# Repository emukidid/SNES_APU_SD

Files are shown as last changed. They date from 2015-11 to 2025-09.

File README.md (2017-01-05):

# SNES_APU_SD
Drives a SNES APU from early Super Nintendo/Super Famicom consoles with an arduino to load tracks from SD Card

Based on code written by [CaitSith2]

### Current Features
- Loads a .spc file from SD card and plays it on the SNES APU
- Loads a .spc file through the PC interface.
- 16x2 LCD for track display and menu
- Menu with file selection
- SRAM to cache tracks (CaitSith2)
- Interface APU as direct memory (CaitSith2)

### Planned Features
- RTC for nice things

### Hardware required
- Early NTSC SNES or Super Famicom with modular APU
- Arduino Mega
- APU Arduino Shield (Work In Progress)
- Love for 16-bit SNES music

[caitsith2]:  <https://www.caitsith2.com/snes/apu.htm>

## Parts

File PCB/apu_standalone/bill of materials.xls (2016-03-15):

Digi-Key Part Number | Manufacturer | Manufacturer Part Number | Customer Reference | Quantity 1 | Quantity 2 | Quantity 3 | Mfg Std Lead Time | Description | Comments | RoHS Status | Lead Free Status | REACH Status
CP-1401-ND | CUI INC | RCJ-012 | RIGHT RCA | 1 | 0 | 0 | 8 Weeks | CONN RCA JACK METAL R/A RED PCB |  | RoHS Compliant | Lead free | Not Available
CP-1402-ND | CUI INC | RCJ-013 | LEFT RCA | 1 | 0 | 0 | 8 Weeks | CONN RCA JACK METAL R/A WHT PCB |  | RoHS Compliant | Lead free | Not Available
CP1-3533N-ND | CUI INC | SJ1-3533N | HEADPHONE, LINEOUT | 2 | 0 | 0 | 9 Weeks | CONN JACK STEREO R/A 3PIN 3.5MM |  | RoHS Compliant | Lead free | Not Available
SY033-ND | FDK AMERICA INC | CR1220 | RTC BATTERY | 1 | 0 | 0 | 16 Weeks | BATTERY LITHIUM 3V COIN 12.5MM |  | RoHS compliant by exemption | Lead free | Not Available
1276-1007-1-ND | SAMSUNG ELECTRO-MECHANICS AMERICA, INC (VA) | CL21F104ZBCNNNC | C1, C2, C7, C15..C19, C22..C31 | 18 | 0 | 0 | 13 Weeks | CAP CER 0.1UF 50V Y5V 0805 | Alternate Packaging Exists | RoHS Compliant | Lead free | Unaffected Dec-2014
311-1.0KARCT-ND | YAGEO (VA) | RC0805JR-071KL | R6, R26, R27 | 3 | 0 | 0 | 22 Weeks | RES SMD 1K OHM 5% 1/8W 0805 | Alternate Packaging Exists | RoHS Compliant | Lead free | Unaffected Jun-2015
475-1415-1-ND | OSRAM OPTO SEMICONDUCTORS INC(VA) | LH R974-LP-1 | ACT, RX, TX | 3 | 0 | 0 | 12 Weeks | LED RED DIFFUSED 0805 SMD | Alternate Packaging Exists | RoHS Compliant | Lead free | Unaffected Jun-2015
SW400-ND | OMRON ELECTRONICS INC-EMC DIV | B3F-1000 |  | 8 | 0 | 0 | 14 Weeks | SWITCH TACTILE SPST-NO 0.05A 24V |  | RoHS Compliant | Lead free | Not Available
WM12834CT-ND | MOLEX, LLC (VA) | 5031821852 | SD HOLDER | 1 | 0 | 0 | 8 Weeks | MICRO SD NORMAL ULTRALOWPRO8CKTE | Alternate Packaging Exists | RoHS Compliant | Lead free | Not Available
568-8150-1-ND | NXP SEMICONDUCTORS (VA) | 74HC4050D,653 | IC2 | 1 | 0 | 0 | 16 Weeks | IC HEX LEVEL SHIFTER 16SOIC | Alternate Packaging Exists | RoHS Compliant | Lead free | Unaffected Jun-2015
296-18476-1-ND | TEXAS INSTRUMENTS (VA) | LP2985-33DBVR | LP298X | 1 | 0 | 0 | 6 Weeks | IC REG LDO 3.3V 0.15A SOT23-5 | Alternate Packaging Exists | RoHS Compliant | Lead free | Unaffected Dec-2014
399-3684-1-ND | KEMET (VA) | T491A106K010AT | C8 | 1 | 0 | 0 | 2 Weeks | CAP TANT 10UF 10V 10% 1206 | Alternate Packaging Exists | RoHS Compliant | Lead free | Unaffected Jun-2014
296-4612-1-ND | TEXAS INSTRUMENTS (VA) | SN74AHC573DWR | IC1 | 1 | 0 | 0 | 6 Weeks | IC OCT TRNSP D-TYP LATCH 20-SOIC | Alternate Packaging Exists | RoHS Compliant | Lead free | Unaffected Dec-2014
706-1041-ND | ISSI | IS62C1024AL-35QLI | IC11 | 1 | 0 | 0 | 10 Weeks | IC SRAM 1MBIT 35NS 32SOP | Alternate Packaging Exists | RoHS Compliant | Lead free | Unaffected Dec-2014
SAM1067-50-ND | SAMTEC INC | TSW-150-17-T-S | 8-8-8-8-8-10 | 1 | 0 | 0 | 2 Weeks | CONN HEADER 50POS .100" SNGL TIN |  | RoHS Compliant | Lead free | Unaffected Jun-2015
SAM1067-36-ND | SAMTEC INC (VA) | TSW-136-17-T-S | 18-18 | 1 | 0 | 0 |  | CONN HEADER 36POS .100" SNGL TIN | No delivery date available | RoHS Compliant | Lead free | Unaffected Jun-2015
3306W-103-ND | BOURNS INC | 3306W-1-103 | 10K TRIM POT | 1 | 0 | 0 | 18 Weeks | TRIMMER 10K OHM 0.2W PC PIN |  | RoHS Compliant | Lead free | Unaffected Jun-2015
NHD-0216BZ-FL-YBW-ND | NEWHAVEN DISPLAY INTL | NHD-0216BZ-FL-YBW | LCD | 1 | 0 | 0 | 16 Weeks | LCD MOD CHAR 2X16 Y/G TRANSFL |  | RoHS Compliant | Lead free | Unaffected Jun-2015
311-10KARCT-ND | YAGEO (VA) | RC0805JR-0710KL | R2,R3,R7,R10,R11,R12,R13,R14,R15 | 9 | 0 | 0 | 22 Weeks | RES SMD 10K OHM 5% 1/8W 0805 | Alternate Packaging Exists | RoHS Compliant | Lead free | Unaffected Jun-2015
311-2.2KARCT-ND | YAGEO (VA) | RC0805JR-072K2L | R8, R9 | 2 | 0 | 0 | 22 Weeks | RES SMD 2.2K OHM 5% 1/8W 0805 | Alternate Packaging Exists | RoHS Compliant | Lead free | Unaffected Jun-2015
311-22KARCT-ND | YAGEO (VA) | RC0805JR-0722KL | R16, R17, R18, R19, R20, R21 | 6 | 0 | 0 | 22 Weeks | RES SMD 22K OHM 5% 1/8W 0805 | Alternate Packaging Exists | RoHS Compliant | Lead free | Unaffected Jun-2015
311-5.1KARCT-ND | YAGEO (VA) | RC0805JR-075K1L | R22, R23 | 2 | 0 | 0 | 22 Weeks | RES SMD 5.1K OHM 5% 1/8W 0805 | Alternate Packaging Exists | RoHS Compliant | Lead free | Unaffected Jun-2015
311-49.9CRCT-ND | YAGEO (VA) | RC0805FR-0749R9L | R4, R5 | 2 | 0 | 0 | 22 Weeks | RES SMD 49.9 OHM 1% 1/8W 0805 | Alternate Packaging Exists | RoHS Compliant | Lead free | Unaffected Jun-2015
497-1561-1-ND | STMICROELECTRONICS (VA) | LM2904DT | IC7 | 1 | 0 | 0 | 12 Weeks | IC OPAMP GP 1.1MHZ 8SO | Alternate Packaging Exists | RoHS Compliant | Lead free | Unaffected Jul-2011
DS1307Z+T&RCT-ND | MAXIM INTEGRATED (VA) | DS1307Z+T&R | IC3 | 1 | 0 | 0 | 10 Weeks | IC RTC CLK/CALENDAR I2C 8-SOIC | Alternate Packaging Exists | RoHS Compliant | Lead free | Unaffected Jun-2012
XC1911CT-ND | ECS INC (VA) | ECS-.327-12.5-13FLX-C | Q1 | 1 | 0 | 0 | 14 Weeks | CRYSTAL 32.7680KHZ 12.5PF SMD | Alternate Packaging Exists | RoHS Compliant | Lead free | Unaffected Dec-2014
BK-885-CT-ND | MEMORY PROTECTION DEVICES (VA) | BK-885-TR | CR1220 | 1 | 0 | 0 | 10 Weeks | HOLDER COIN CELL 12MM SMD | Alternate Packaging Exists | RoHS Compliant | Lead free | Unaffected Jun-2015
311-1365-1-ND | YAGEO (VA) | CC0805KKX7R7BB105 | C3,C4,C5,C6 | 4 | 0 | 0 | 21 Weeks | CAP CER 1UF 16V X7R 0805 | Alternate Packaging Exists | RoHS Compliant | Lead free | Unaffected Jun-2015
399-1136-1-ND | KEMET (VA) | C0805C102J5GACTU | C9,C12 | 2 | 0 | 0 | 10 Weeks | CAP CER 1000PF 50V NP0 0805 | Alternate Packaging Exists | RoHS Compliant | Lead free | Unaffected Jun-2014
399-1122-1-ND | KEMET (VA) | C0805C101J5GACTU | C10,C13 | 2 | 0 | 0 | 5 Weeks | CAP CER 100PF 50V NP0 0805 | Alternate Packaging Exists | RoHS Compliant | Lead free | Unaffected Jun-2014
311-1092-1-ND | YAGEO (VA) | CC0805CRNPO9BN3R0 | C20,C21 | 2 | 0 | 0 | 21 Weeks | CAP CER 3PF 50V NPO 0805 | Alternate Packaging Exists | RoHS Compliant | Lead free | Unaffected Jun-2015
445-7505-1-ND | TDK CORPORATION (VA) | C2012C0G1H182J060AA | C11,C14 | 2 | 0 | 0 | 12 Weeks | CAP CER 1800PF 50V C0G 0805 | Alternate Packaging Exists | RoHS Compliant | Lead free | Unaffected Jun-2015
706-1043-ND | ISSI | IS62C256AL-45ULI | IC8, IC9 | 2 | 0 | 0 | 12 Weeks | IC SRAM 256KBIT 45NS 28SOP | Alternate Packaging Exists | RoHS Compliant | Lead free | Unaffected Dec-2014
3M9454-ND | 3M | 961116-6404-AR | LCD MALE PINS | 1 | 0 | 0 | 8 Weeks | CONN HEADER VERT SGL 16POS GOLD |  | RoHS Compliant | Lead free | Not Available
S7049-ND | SULLINS CONNECTOR SOLUTIONS | PPPC161LFBN-RC | LCD FEMALE SOCKET | 1 | 0 | 0 | 4 Weeks | CONN HEADER FMALE 16POS .1" GOLD |  | RoHS Compliant | Lead free | Unaffected Dec-2014
ATMEGA2560-16AU-ND | ATMEL | ATMEGA2560-16AU | IC12 | 1 | 0 | 0 | 6 Weeks | IC MCU 8BIT 256KB FLASH 100TQFP | Alternate Packaging Exists | RoHS Compliant | Lead free | Unaffected Jun-2015
768-1007-1-ND | FTDI (VA) | FT232RL-REEL | IC15 | 1 | 0 | 0 | 12 Weeks | IC USB FS SERIAL UART 28-SSOP | Alternate Packaging Exists | RoHS Compliant | Lead free | Unaffected Jun-2015
ED2983-ND | ON SHORE TECHNOLOGY INC | USB-B1HSB6 | X4 | 1 | 0 | 0 | 8 Weeks | CONN USB TYPE B R/A BLACK |  | RoHS Compliant | Lead free | Unaffected Jun-2015
535-10008-1-ND | ABRACON LLC (VA) | AWSCR-16.00CV-T | Y1 | 1 | 0 | 0 | 11 Weeks | RESONATOR CER 16.00MHZ W/CAP SMD | Alternate Packaging Exists | RoHS Compliant | Lead free | Unaffected Jun-2015
311-1.00MCRCT-ND | YAGEO (VA) | RC0805FR-071ML | R1 | 1 | 0 | 0 | 22 Weeks | RES SMD 1M OHM 1% 1/8W 0805 | Alternate Packaging Exists | RoHS Compliant | Lead free | Unaffected Jun-2015
283-3140-1-ND | EATON BUSSMANN (VA) | PTS120615V050 | F1 | 1 | 0 | 0 | 11 Weeks | PTC RESETTABLE SMD 1206 15V 0.5A |  | RoHS Compliant | Lead free | Unaffected Jul-2011

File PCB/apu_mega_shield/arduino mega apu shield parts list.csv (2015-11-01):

QTY | Part | Digikey Part Number
1 | RCA Red | CP-1401-ND
1 | RCA White | CP-1402-ND
2 | 3.5mm female TRS | CP1-3533N-ND
2 | 50ohm resistor | 51QBK-ND
4 | 1uF capacitor | BC1162CT-ND
1 | 32.768 khz crystal | X1123-ND
1 | DS1307 RTC | DS1307+-ND
1 | CR1220 holder | BK-890-ND
2 | 2.2K resistor | 2.2KQBK-ND
3 | 0.1uF Capacitor,(0805) | 1276-1007-1-ND
1 | 1K resistor (0805) | 311-1.0KARCT-ND
1 | Red LED,(0805) | 475-1415-1-ND
8 | buttons | SW400-ND
1 | Micro SD holder | WM10795CT-ND
1 | 4050D buffer chip | 568-8150-1-ND
1 | LP298X 3.3v Regulator | 296-18476-1-ND
1 | 10uF 10V Capacitor (1206) | 399-3684-1-ND
1 | 74HCT573 Octal Latch | 296-4612-1-ND
1 | IS62C1024AL-35QLI Sram chip | 706-1041-ND
1 | 50 pin breakaway headers | SAM1067-50-ND
1 | 36 pin breakaway headers | SAM1067-36-ND
1 | 16 pin header | SAM1067-16-ND
1 | 16 pin socket | SAM1198-16-ND
1 | 10K trim pot | 3306W-103-ND
1 | 10K 9 resistor network. | 4610X-1-103LF-ND
1 | 16x2 LCD character display. | NHD-0216BZ-FL-YBW-ND
1 | 220ohm resistor | 220QBK-ND

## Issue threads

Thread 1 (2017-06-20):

Interested in...

thErZAgH, 2017-06-20:
Hi.

I'm highly interested in using the awesome player on Arduino Uno. Is this possible? Which version of Arduino can I use to compile the code for Arduino Uno?

Thank you in advance...

ZapDragon, 2018-12-29:
Simply, you cannot use an Uno. It just doesnt have the pins needed for this setup.
SD card, LCD, Buttons, APU Interface, SRAM, ect.
There is just too much happening.

I am building this myself, and I understand why a Mega is used. If you want to build this I strongly recommend following everything in the source files to the letter.

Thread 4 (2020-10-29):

SPC play issue

VargSilvermane, 2020-10-29:
When playing a track the first note is played, hangs on the note and fades after a second. No further notes are played.

Hardware used:
Mega Shield with integrated APU
Arduino Mega 2560 r3

Software:
Arduino IDE 1.8.13
SDFAT by Bill Greiman
RTClib by Adafruit

emukidid, 2020-10-31:
Try messing with the PRESCALER value in the .ino, some mega clones have issues with the default speed.

VargSilvermane, 2020-10-31:
No luck, I tried a prescaler of 1 and 2. I should also mention the arduino _should_ be a genuine unit, barring an counterfeit chip on arduinos product, seeing as I purchased it from them.

Oj5000, 2021-11-12:
Any luck getting this working? Could be to do with the changes made in v3 of the hardware

VargSilvermane, 2021-12-05:
Yes, though it was a while ago. Trying to remember, I believe it had to do with the SDFAT library and compatibility with various capacity SD cards. I ended up swapping out the library with another version and managed to get it working well. Incidentally I remade the hardware into a more portable format since the original post. (handheld case with upgraded screen and battery/charger)

Closed 2021-12-05.

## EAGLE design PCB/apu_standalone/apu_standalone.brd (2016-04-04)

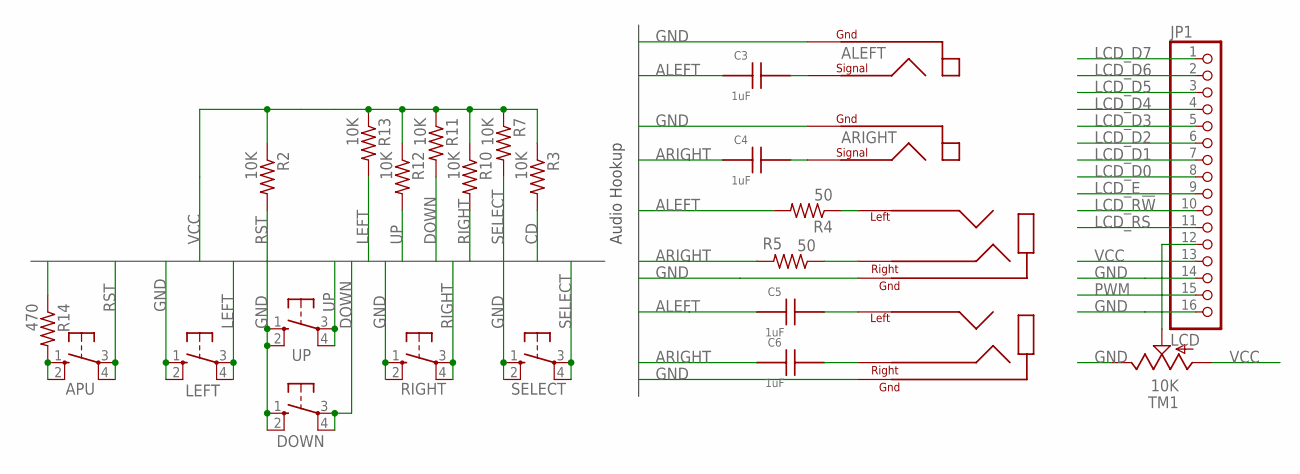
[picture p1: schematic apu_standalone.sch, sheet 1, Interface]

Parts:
APU: Reset; B3F-10XX
C3, C4, C5, C6: 1uF; C0805
DOWN: DOWN; B3F-10XX
JP1: LCD; 1X16
LEFT: LEFT; B3F-10XX
R2, R3, R7, R10, R11, R12, R13: 10K; R0805
R4, R5: 50; R0805
R14: 470; R0805
RIGHT: RIGHT; B3F-10XX
SELECT: SELECT; B3F-10XX
TM1: 10K; CA6H
U$2, U$3: HEADPHONE; SJ1-3533N
U$4, U$5: RCA; RCJ-01X
UP: UP; B3F-10XX

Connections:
ALEFT: C3.1, C5.1, R4.2; also elsewhere on the board
ARIGHT: C4.1, C6.1, R5.2; also elsewhere on the board
CD: R3.2; also elsewhere on the board
DOWN: DOWN.3, DOWN.4 (P1), R11.2; also elsewhere on the board
GND: DOWN.1 (S), DOWN.2 (S1), JP1.14, JP1.16, LEFT.1 (S), LEFT.2 (S1), R14.1, RIGHT.1 (S), RIGHT.2 (S1), SELECT.1 (S), SELECT.2 (S1), TM1.E, U$2.GND, U$3.GND, U$4.PGND1, U$4.PGND2, U$4.PGND3, U$5.PGND1, U$5.PGND2, U$5.PGND3, UP.1 (S), UP.2 (S1); also elsewhere on the board
LCD_D0: JP1.8; also elsewhere on the board
LCD_D1: JP1.7; also elsewhere on the board
LCD_D2: JP1.6; also elsewhere on the board
LCD_D3: JP1.5; also elsewhere on the board
LCD_D4: JP1.4; also elsewhere on the board
LCD_D5: JP1.3; also elsewhere on the board
LCD_D6: JP1.2; also elsewhere on the board
LCD_D7: JP1.1; also elsewhere on the board
LCD_E: JP1.9; also elsewhere on the board
LCD_R!W: JP1.10; also elsewhere on the board
LCD_RS: JP1.11; also elsewhere on the board
LEFT: LEFT.3, LEFT.4 (P1), R13.2; also elsewhere on the board
unnamed: C3.2, U$4.PSIG
unnamed: C4.2, U$5.PSIG
unnamed: C5.2, U$3.LEFT
unnamed: APU.1 (S), APU.2 (S1), R14.2
unnamed: C6.2, U$3.RIGHT
unnamed: R4.1, U$2.LEFT
unnamed: R5.1, U$2.RIGHT
unnamed: JP1.12, TM1.S
PWM: JP1.15; also elsewhere on the board
RIGHT: R10.2, RIGHT.3, RIGHT.4 (P1); also elsewhere on the board
RST: APU.3, APU.4 (P1), R2.2; also elsewhere on the board
SELECT: R7.2, SELECT.3, SELECT.4 (P1); also elsewhere on the board
UP: R12.2, UP.3, UP.4 (P1); also elsewhere on the board
VCC: JP1.13, R2.1, R3.1, R7.1, R10.1, R11.1, R12.1, R13.1, TM1.A; also elsewhere on the board

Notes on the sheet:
Audio Hookup

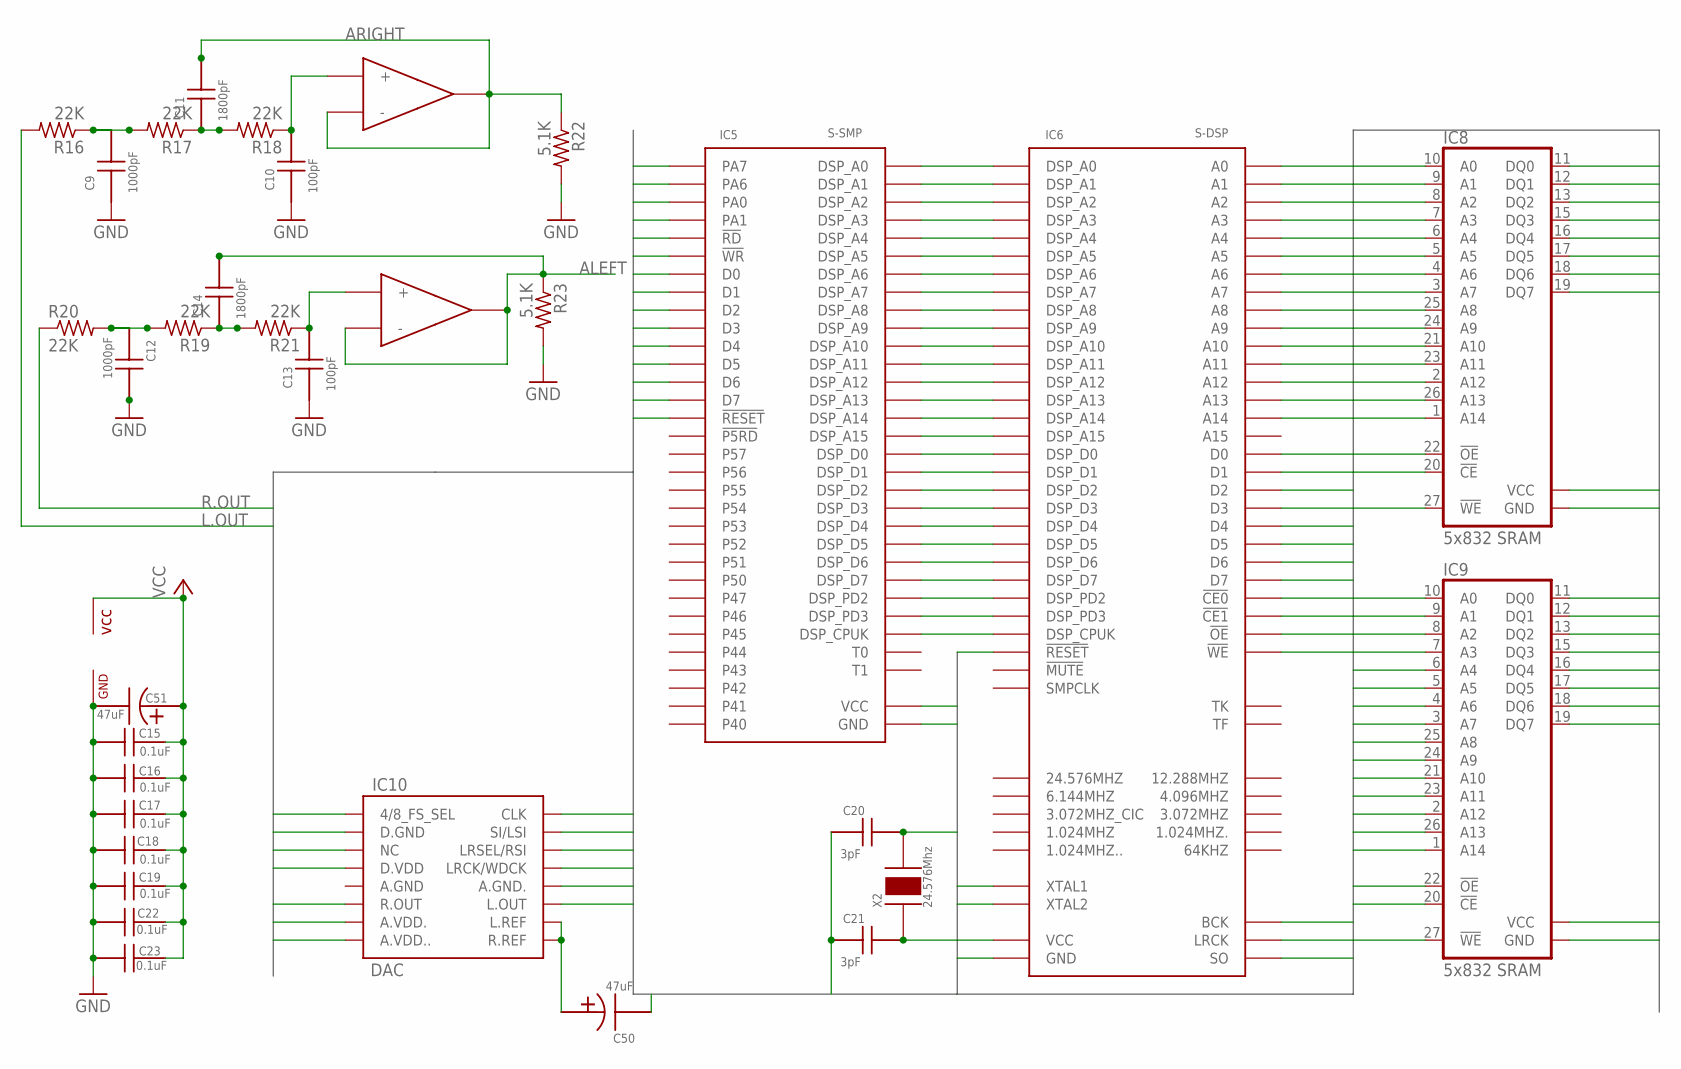
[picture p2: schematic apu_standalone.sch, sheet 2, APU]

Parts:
C9, C12: 1000pF; C0805
C10, C13: 100pF; C0805
C11, C14: 1800pF; C0805
C15, C16, C17, C18, C19, C22, C23: 0.1uF; C0805
C20, C21: 3pF; C0805
C50, C51: 47uF; TT5D6
IC5: S-SMP; QFP64_SOT319
IC6: S-DSP; QFP80_SOT318
IC7: LM2904; SO-08
IC8, IC9: 5x832 SRAM; SO28X
IC10: DAC; SO16W
R16, R17, R18, R19, R20, R21: 22K; R0805
R22, R23: 5.1K; R0805
X2: 24.576Mhz; QS

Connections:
!CE0: IC6.28 (!CE0), IC8.20 (!CE)
!CE1: IC6.27 (!CE1), IC9.20 (!CE)
!OE: IC6.30 (!OE), IC8.22 (!OE), IC9.22 (!OE)
!RD: IC5.46 (!RD); also elsewhere on the board
!WE: IC6.36 (!WE), IC8.27 (!WE), IC9.27 (!WE)
!WR: IC5.47 (!WR); also elsewhere on the board
A10: IC5.49 (PA0); also elsewhere on the board
A11: IC5.48 (PA1); also elsewhere on the board
A15: IC5.51 (PA7); also elsewhere on the board
A18: IC6.9 (A0), IC8.10 (A0), IC9.10 (A0)
A19: IC6.10 (A1), IC8.9 (A1), IC9.9 (A1)
A20: IC6.11 (A2), IC8.8 (A2), IC9.8 (A2)
A21: IC6.13 (A3), IC8.7 (A3), IC9.7 (A3)
A22: IC6.14 (A4), IC8.6 (A4), IC9.6 (A4)
A23: IC6.15 (A5), IC8.5 (A5), IC9.5 (A5)
A24: IC6.16 (A6), IC8.4 (A6), IC9.4 (A6)
A25: IC6.17 (A7), IC8.3 (A7), IC9.3 (A7)
A26: IC6.34 (A8), IC8.25 (A8), IC9.25 (A8)
A27: IC6.32 (A9), IC8.24 (A9), IC9.24 (A9)
A28: IC6.29 (A10), IC8.21 (A10), IC9.21 (A10)
A29: IC6.31 (A11), IC8.23 (A11), IC9.23 (A11)
A30: IC6.18 (A12), IC8.2 (A12), IC9.2 (A12)
A31: IC6.35 (A13), IC8.26 (A13), IC9.26 (A13)
A32: IC6.19 (A14), IC8.1 (A14), IC9.1 (A14)
A.REF: C50.+, IC10.9 (R.REF), IC10.10 (L.REF)
ALEFT: C14.2, IC7.6 (-), IC7.7 (OUT), R23.1; also elsewhere on the board
ARIGHT: C11.2, IC7.1 (OUT), IC7.2 (-), R22.1; also elsewhere on the board
BCK: IC6.42 (BCK), IC10.16 (CLK)
D0: IC5.45 (D0); also elsewhere on the board
D1: IC5.44 (D1); also elsewhere on the board
D2: IC5.43 (D2); also elsewhere on the board
D3: IC5.42 (D3); also elsewhere on the board
D4: IC5.41 (D4); also elsewhere on the board
D5: IC5.40 (D5); also elsewhere on the board
D6: IC5.39 (D6); also elsewhere on the board
D7: IC5.38 (D7); also elsewhere on the board
D8: IC6.8 (D0), IC8.11 (DQ0), IC9.11 (DQ0)
D9: IC6.7 (D1), IC8.12 (DQ1), IC9.12 (DQ1)
D10: IC6.6 (D2), IC8.13 (DQ2), IC9.13 (DQ2)
D11: IC6.22 (D3), IC8.15 (DQ3), IC9.15 (DQ3)
D12: IC6.23 (D4), IC8.16 (DQ4), IC9.16 (DQ4)
D13: IC6.24 (D5), IC8.17 (DQ5), IC9.17 (DQ5)
D14: IC6.25 (D6), IC8.18 (DQ6), IC9.18 (DQ6)
D15: IC6.26 (D7), IC8.19 (DQ7), IC9.19 (DQ7)
DSP_A0: IC5.5 (DSP_A0), IC6.60 (DSP_A0)
DSP_A1: IC5.4 (DSP_A1), IC6.61 (DSP_A1)
DSP_A2: IC5.3 (DSP_A2), IC6.62 (DSP_A2)
DSP_A3: IC5.2 (DSP_A3), IC6.63 (DSP_A3)
DSP_A4: IC5.1 (DSP_A4), IC6.64 (DSP_A4)
DSP_A5: IC5.64 (DSP_A5), IC6.65 (DSP_A5)
DSP_A6: IC5.63 (DSP_A6), IC6.66 (DSP_A6)
DSP_A7: IC5.62 (DSP_A7), IC6.67 (DSP_A7)
DSP_A8: IC5.61 (DSP_A8), IC6.68 (DSP_A8)
DSP_A9: IC5.60 (DSP_A9), IC6.69 (DSP_A9)
DSP_A10: IC5.59 (DSP_A10), IC6.70 (DSP_A10)
DSP_A11: IC5.56 (DSP_A11), IC6.71 (DSP_A11)
DSP_A12: IC5.55 (DSP_A12), IC6.72 (DSP_A12)
DSP_A13: IC5.54 (DSP_A13), IC6.74 (DSP_A13)
DSP_A14: IC5.53 (DSP_A14), IC6.75 (DSP_A14)
DSP_A15: IC5.52 (DSP_A15), IC6.76 (DSP_A15)
DSP_CPUK: IC5.16 (DSP_CPUK), IC6.48 (DSP_CPUK)
DSP_D0: IC5.13 (DSP_D0), IC6.51 (DSP_D0)
DSP_D1: IC5.12 (DSP_D1), IC6.53 (DSP_D1)
DSP_D2: IC5.11 (DSP_D2), IC6.54 (DSP_D2)
DSP_D3: IC5.10 (DSP_D3), IC6.55 (DSP_D3)
DSP_D4: IC5.9 (DSP_D4), IC6.56 (DSP_D4)
DSP_D5: IC5.8 (DSP_D5), IC6.57 (DSP_D5)
DSP_D6: IC5.7 (DSP_D6), IC6.58 (DSP_D6)
DSP_D7: IC5.6 (DSP_D7), IC6.59 (DSP_D7)
DSP_PD2: IC5.15 (DSP_PD2), IC6.49 (DSP_PD2)
DSP_PD3: IC5.14 (DSP_PD3), IC6.50 (DSP_PD3)
GND: C9.1, C10.1, C12.2, C13.1, C15.2, C16.2, C17.2, C18.2, C19.2, C20.1, C21.1, C22.1, C23.2, C50.-, C51.-, IC5.26 (GND), IC5.58 (GND), IC6.12 (GND), IC6.52 (GND), IC7.4 (GND), IC8.14 (GND), IC9.14 (GND), IC10.1 (4/8_FS_SEL), IC10.2 (D.GND), IC10.12 (A.GND.), IC10.14 (LRSEL/RSI), R22.2, R23.2; also elsewhere on the board
L1: C12.1, R19.2, R20.2
L2: C14.1, R19.1, R21.2
L3: C13.2, IC7.5 (+), R21.1
L.OUT: IC10.11 (L.OUT), R16.2
LRCK: IC6.43 (LRCK), IC10.13 (LRCK/WDCK)
R1: C9.2, R16.1, R17.2
R2: C11.1, R17.1, R18.2
R3: C10.2, IC7.3 (+), R18.1
R.OUT: IC10.6 (R.OUT), R20.1
RST: IC5.37 (!RESET), IC6.47 (!RESET); also elsewhere on the board
SO: IC6.44 (SO), IC10.15 (SI/LSI)
VCC: C15.1, C16.1, C17.1, C18.1, C19.1, C22.2, C23.1, C51.+, IC5.50 (PA6), IC5.57 (VCC), IC6.33 (VCC), IC6.73 (VCC), IC7.8 (VCC), IC8.28 (VCC), IC9.28 (VCC), IC10.3 (NC), IC10.4 (D.VDD), IC10.7 (A.VDD.), IC10.8 (A.VDD..); also elsewhere on the board
XTAL1: C21.2, IC6.45 (XTAL1), X2.1
XTAL2: C20.2, IC6.46 (XTAL2), X2.2

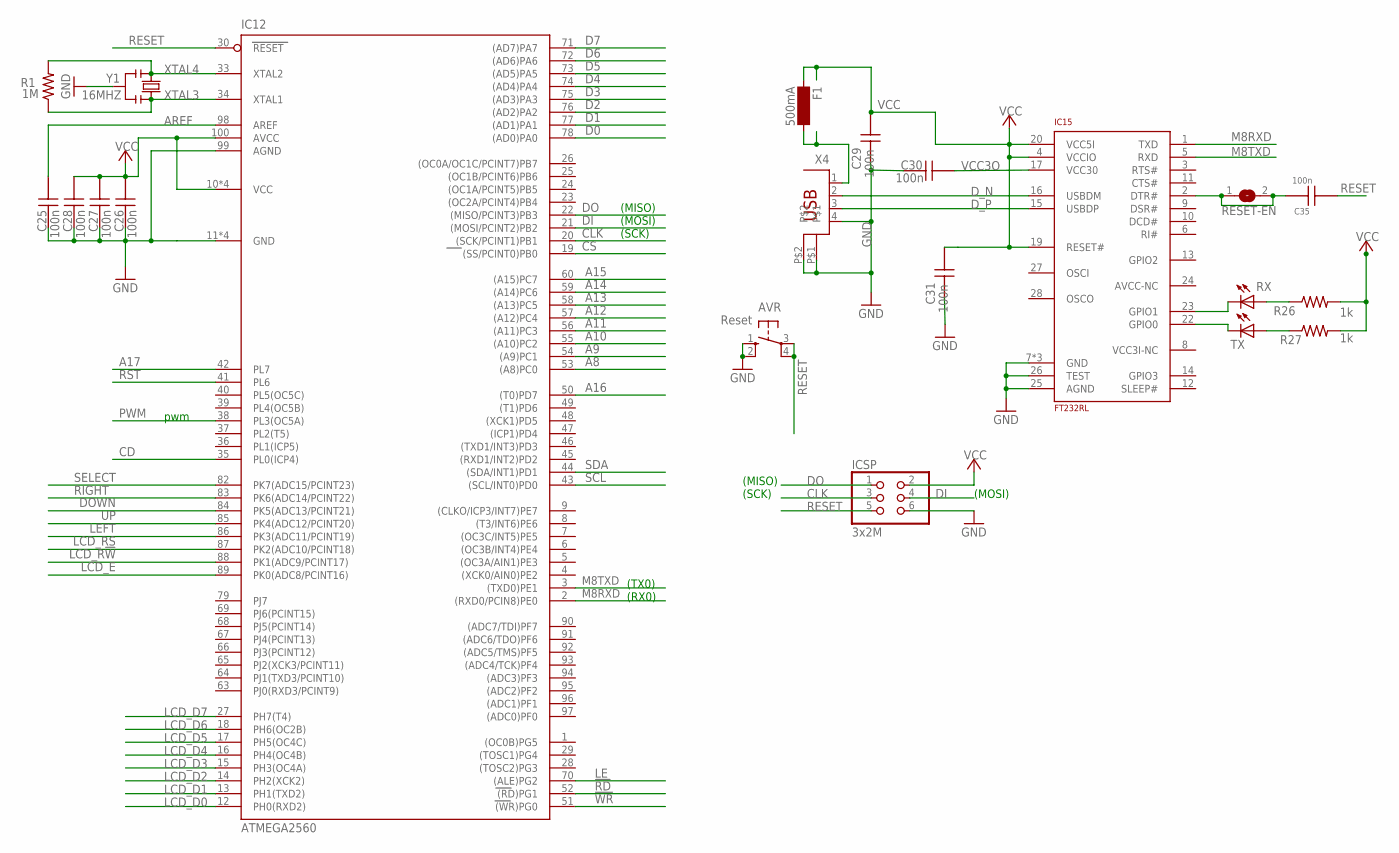
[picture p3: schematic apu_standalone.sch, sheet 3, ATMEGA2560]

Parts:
AVR: Reset; B3F-10XX
C25, C26, C27, C28, C29, C30, C31, C35: 100n; C0805
F1: 500mA; SM-1206
IC12: ATMEGA2560; TQFP100
IC15: FT232RL; SSOP28
ICSP: 3x2M; 2X03
R1: 1M; R0805
R26, R27: 1k; R0805
RESET-EN: SJ
RX: LEDCHIP-LED0805; CHIP-LED0805
TX: LEDCHIP-LED0805; CHIP-LED0805
X4: PN61729
Y1: 16MHZ; RESONATOR

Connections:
!RD: IC12.52 ((RD)PG1); also elsewhere on the board
!WR: IC12.51 ((WR)PG0); also elsewhere on the board
A8: IC12.53 ((A8)PC0); also elsewhere on the board
A9: IC12.54 ((A9)PC1); also elsewhere on the board
A10: IC12.55 ((A10)PC2); also elsewhere on the board
A11: IC12.56 ((A11)PC3); also elsewhere on the board
A12: IC12.57 ((A12)PC4); also elsewhere on the board
A13: IC12.58 ((A13)PC5); also elsewhere on the board
A14: IC12.59 ((A14)PC6); also elsewhere on the board
A15: IC12.60 ((A15)PC7); also elsewhere on the board
A16: IC12.50 ((T0)PD7); also elsewhere on the board
A17: IC12.42 (PL7); also elsewhere on the board
AREF: C25.1, IC12.98 (AREF)
CD: IC12.35 (PL0(ICP4)); also elsewhere on the board
CLK: IC12.20 ((SCK/PCINT1)PB1), ICSP.3; also elsewhere on the board
CS: IC12.19 ((SS/PCINT0)PB0); also elsewhere on the board
D0: IC12.78 ((AD0)PA0); also elsewhere on the board
D1: IC12.77 ((AD1)PA1); also elsewhere on the board
D2: IC12.76 ((AD2)PA2); also elsewhere on the board
D3: IC12.75 ((AD3)PA3); also elsewhere on the board
D4: IC12.74 ((AD4)PA4); also elsewhere on the board
D5: IC12.73 ((AD5)PA5); also elsewhere on the board
D6: IC12.72 ((AD6)PA6); also elsewhere on the board
D7: IC12.71 ((AD7)PA7); also elsewhere on the board
DI: IC12.21 ((MOSI/PCINT2)PB2), ICSP.4; also elsewhere on the board
DO: IC12.22 ((MISO/PCINT3)PB3), ICSP.1; also elsewhere on the board
DOWN: IC12.84 (PK5(ADC13/PCINT21)); also elsewhere on the board
DTR: C35.1, IC15.2 (DTR#), RESET-EN.1, RESET-EN.2
D_N: IC15.16 (USBDM), X4.2
D_P: IC15.15 (USBDP), X4.3
GND: AVR.1 (S), AVR.2 (S1), C25.2, C26.2, C27.2, C28.2, C29.2, C30.1, C31.2, IC12.11 (GND), IC12.32 (GND), IC12.62 (GND), IC12.81 (GND), IC12.99 (AGND), IC15.7 (GND), IC15.18 (GND), IC15.21 (GND), IC15.25 (AGND), IC15.26 (TEST), ICSP.6, X4.4, X4.P$1, X4.P$2, Y1.2; also elsewhere on the board
LCD_D0: IC12.12 (PH0(RXD2)); also elsewhere on the board
LCD_D1: IC12.13 (PH1(TXD2)); also elsewhere on the board
LCD_D2: IC12.14 (PH2(XCK2)); also elsewhere on the board
LCD_D3: IC12.15 (PH3(OC4A)); also elsewhere on the board
LCD_D4: IC12.16 (PH4(OC4B)); also elsewhere on the board
LCD_D5: IC12.17 (PH5(OC4C)); also elsewhere on the board
LCD_D6: IC12.18 (PH6(OC2B)); also elsewhere on the board
LCD_D7: IC12.27 (PH7(T4)); also elsewhere on the board
LCD_E: IC12.89 (PK0(ADC8/PCINT16)); also elsewhere on the board
LCD_R!W: IC12.88 (PK1(ADC9/PCINT17)); also elsewhere on the board
LCD_RS: IC12.87 (PK2(ADC10/PCINT18)); also elsewhere on the board
LE: IC12.70 ((ALE)PG2); also elsewhere on the board
LEFT: IC12.86 (PK3(ADC11/PCINT19)); also elsewhere on the board
M8RXD: IC12.2 ((RXD0/PCIN8)PE0), IC15.1 (TXD)
M8TXD: IC12.3 ((TXD0)PE1), IC15.5 (RXD)
unnamed: IC15.23 (GPIO1), RX.C
unnamed: IC15.22 (GPIO0), TX.C
unnamed: R26.1, RX.A
unnamed: R27.1, TX.A
unnamed: F1.2, X4.1
PWM: IC12.38 (PL3(OC5A)); also elsewhere on the board
RESET: AVR.3, AVR.4 (P1), C35.2, IC12.30 (RESET), ICSP.5
RIGHT: IC12.83 (PK6(ADC14/PCINT22)); also elsewhere on the board
RST: IC12.41 (PL6); also elsewhere on the board
SCL: IC12.43 ((SCL/INT0)PD0); also elsewhere on the board
SDA: IC12.44 ((SDA/INT1)PD1); also elsewhere on the board
SELECT: IC12.82 (PK7(ADC15/PCINT23)); also elsewhere on the board
UP: IC12.85 (PK4(ADC12/PCINT20)); also elsewhere on the board
VCC: C26.1, C27.1, C28.1, C29.1, C31.1, F1.1, IC12.10 (VCC), IC12.31 (VCC), IC12.61 (VCC), IC12.80 (VCC), IC12.100 (AVCC), IC15.4 (VCCIO), IC15.19 (RESET#), IC15.20 (VCC5I), ICSP.2, R26.2, R27.2; also elsewhere on the board
VCC3O: C30.2, IC15.17 (VCC30)
XTAL3: IC12.34 (XTAL1), R1.1, Y1.3
XTAL4: IC12.33 (XTAL2), R1.2, Y1.1

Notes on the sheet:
pwm
(TX0)
(RX0)
(MISO)
(SCK)
(MOSI)

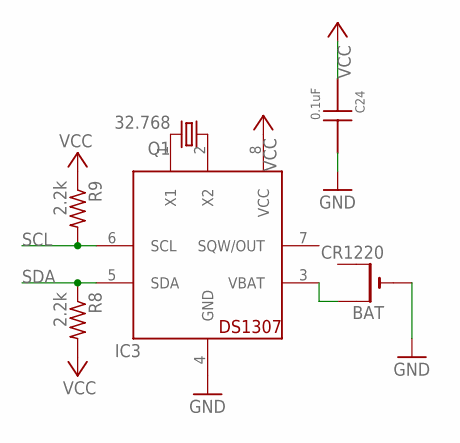
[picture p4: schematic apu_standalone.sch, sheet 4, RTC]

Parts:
BAT: CR1220; CR1220-SMD
C24: 0.1uF; C0805
IC3: DS1307; SO-08
Q1: 32.768; SMD
R8, R9: 2.2k; R0805

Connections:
GND: BAT.-, C24.2, IC3.4 (GND); also elsewhere on the board
unnamed: BAT.+$1 (+), IC3.3 (VBAT)
unnamed: IC3.1 (X1), Q1.2
unnamed: IC3.2 (X2), Q1.1
SCL: IC3.6 (SCL), R9.2; also elsewhere on the board
SDA: IC3.5 (SDA), R8.1; also elsewhere on the board
VCC: C24.1, IC3.8 (VCC), R8.2, R9.1; also elsewhere on the board

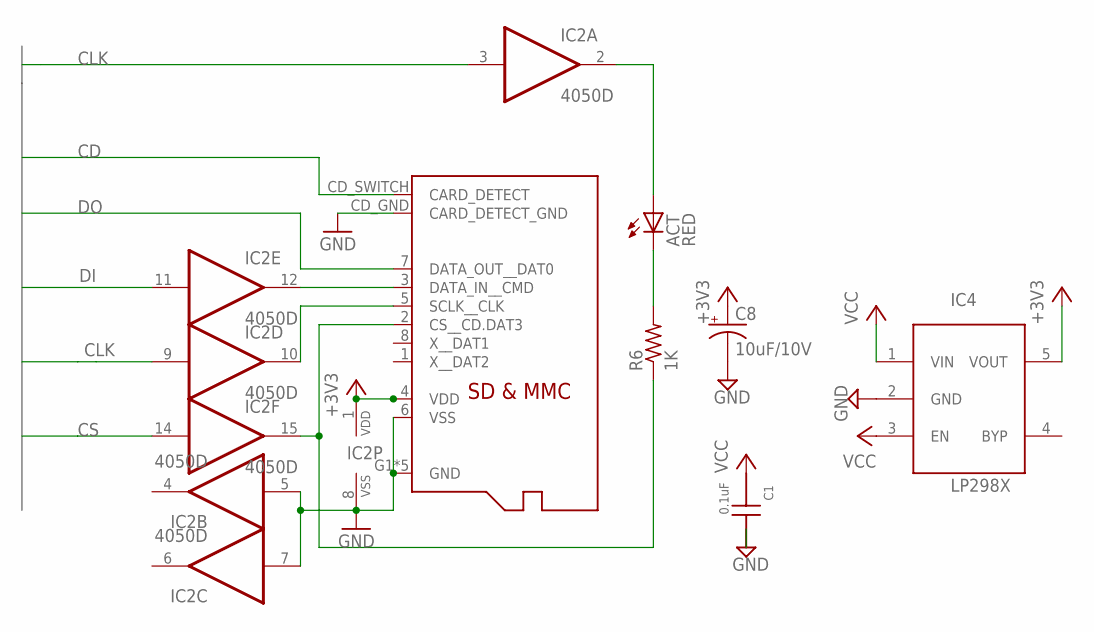
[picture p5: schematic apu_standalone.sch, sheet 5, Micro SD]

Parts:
ACT: RED; CHIP-LED0805
C1: 0.1uF; C0805
C8: 10uF/10V; A/3216-18R
IC2: 4050D; SO16
IC4: LP298XS; SOT23-5L
R6: 1K; R0805
U$1: MICROSD-2; MICROSD-3

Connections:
+3V3: C8.+, IC2.1 (VDD), IC4.5 (VOUT), U$1.4 (VDD)
BUF_CLK: IC2.10 (O), U$1.5 (SCLK__CLK)
BUF_CS: IC2.15 (O), R6.1, U$1.2 (CS__CD.DAT3)
BUF_DI: IC2.12 (O), U$1.3 (DATA_IN__CMD)
BUF_LED: ACT.A, IC2.2 (O)
CD: U$1.CD_SWITCH (CARD_DETECT); also elsewhere on the board
CLK: IC2.3 (I), IC2.9 (I); also elsewhere on the board
CS: IC2.14 (I); also elsewhere on the board
DI: IC2.11 (I); also elsewhere on the board
DO: U$1.7 (DATA_OUT__DAT0); also elsewhere on the board
GND: C1.2, C8.-, IC2.5 (I), IC2.7 (I), IC2.8 (VSS), IC4.2 (GND), U$1.6 (VSS), U$1.CD_GND (CARD_DETECT_GND), U$1.G1 (GND), U$1.G2 (GND), U$1.G3 (GND), U$1.G4 (GND), U$1.G5 (GND); also elsewhere on the board
unnamed: ACT.C, R6.2
VCC: C1.1, IC4.1 (VIN), IC4.3 (EN); also elsewhere on the board

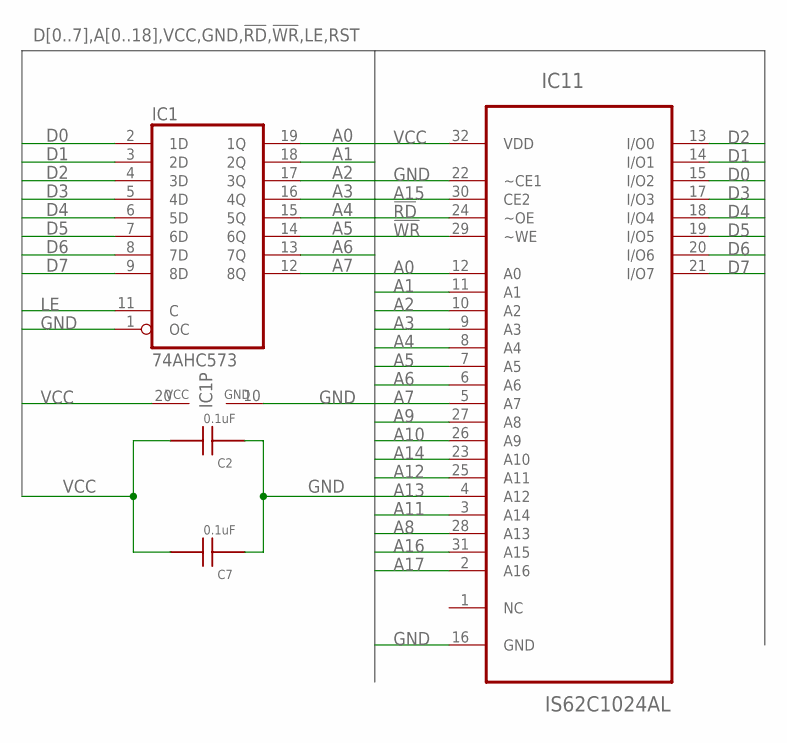
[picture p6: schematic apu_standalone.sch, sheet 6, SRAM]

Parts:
C2, C7: 0.1uF; C0805
IC1: 74AHC573; SO20W
IC11: IS62C1024AL; SOIC127P1412X305-32N

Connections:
!RD: IC11.24 (~OE); also elsewhere on the board
!WR: IC11.29 (~WE); also elsewhere on the board
A0: IC1.19 (1Q), IC11.12 (A0)
A1: IC1.18 (2Q), IC11.11 (A1)
A2: IC1.17 (3Q), IC11.10 (A2)
A3: IC1.16 (4Q), IC11.9 (A3)
A4: IC1.15 (5Q), IC11.8 (A4)
A5: IC1.14 (6Q), IC11.7 (A5)
A6: IC1.13 (7Q), IC11.6 (A6)
A7: IC1.12 (8Q), IC11.5 (A7)
A8: IC11.28 (A13); also elsewhere on the board
A9: IC11.27 (A8); also elsewhere on the board
A10: IC11.26 (A9); also elsewhere on the board
A11: IC11.3 (A14); also elsewhere on the board
A12: IC11.25 (A11); also elsewhere on the board
A13: IC11.4 (A12); also elsewhere on the board
A14: IC11.23 (A10); also elsewhere on the board
A15: IC11.30 (CE2); also elsewhere on the board
A16: IC11.31 (A15); also elsewhere on the board
A17: IC11.2 (A16); also elsewhere on the board
D0: IC1.2 (1D), IC11.15 (I/O2); also elsewhere on the board
D1: IC1.3 (2D), IC11.14 (I/O1); also elsewhere on the board
D2: IC1.4 (3D), IC11.13 (I/O0); also elsewhere on the board
D3: IC1.5 (4D), IC11.17 (I/O3); also elsewhere on the board
D4: IC1.6 (5D), IC11.18 (I/O4); also elsewhere on the board
D5: IC1.7 (6D), IC11.19 (I/O5); also elsewhere on the board
D6: IC1.8 (7D), IC11.20 (I/O6); also elsewhere on the board
D7: IC1.9 (8D), IC11.21 (I/O7); also elsewhere on the board
GND: C2.1, C7.1, IC1.1 (OC), IC1.10 (GND), IC11.16 (GND), IC11.22 (~CE1); also elsewhere on the board
LE: IC1.11 (C); also elsewhere on the board
VCC: C2.2, C7.2, IC1.20 (VCC), IC11.32 (VDD); also elsewhere on the board

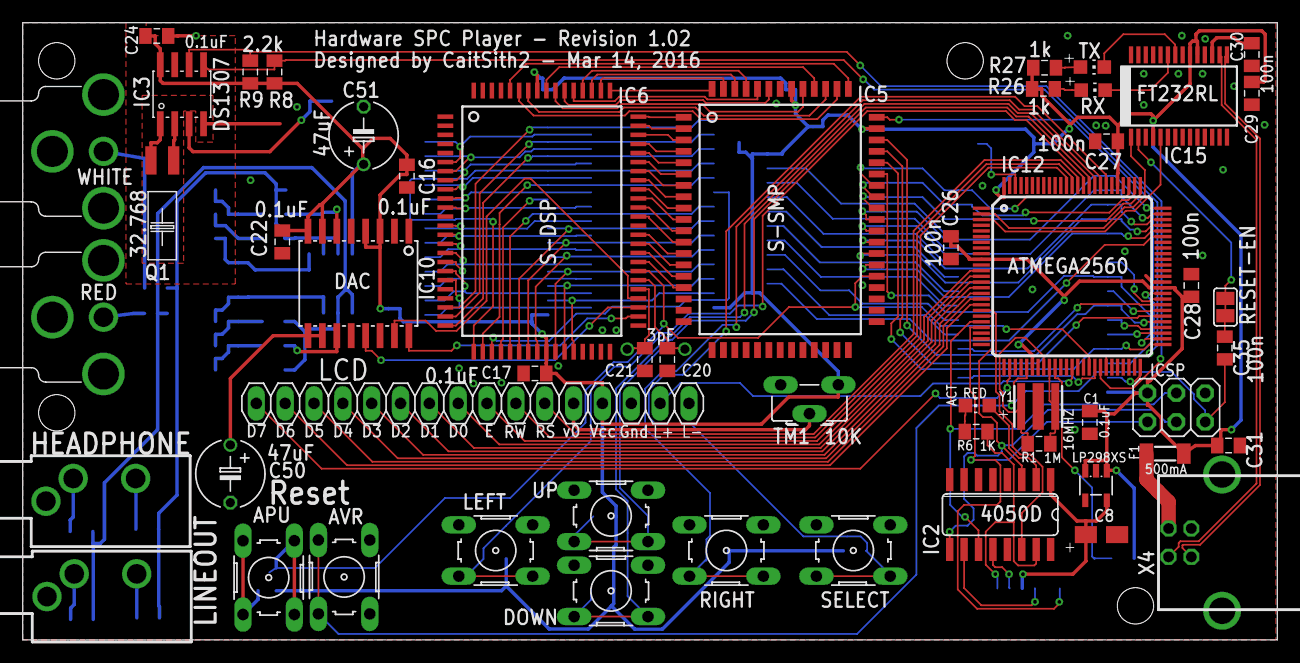
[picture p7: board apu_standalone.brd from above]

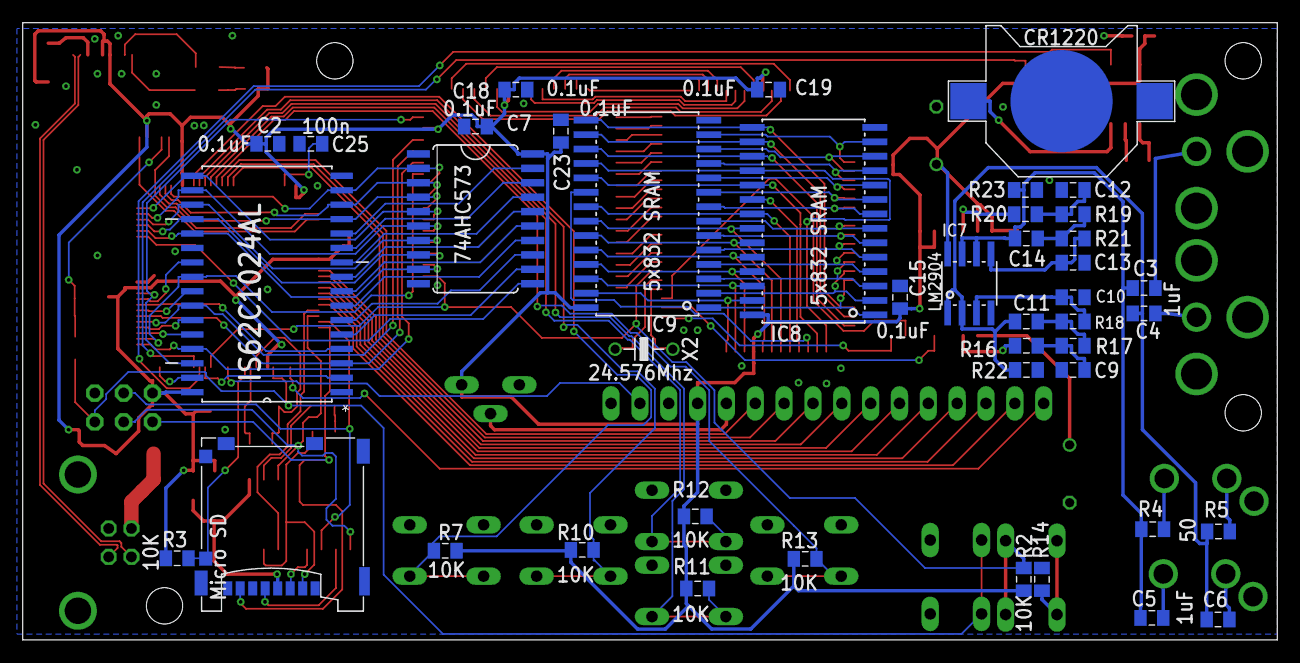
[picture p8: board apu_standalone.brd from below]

Board: 2 copper layers, 110.5 x 54.4 mm, 96 parts (43 on the bottom side), 158 nets.

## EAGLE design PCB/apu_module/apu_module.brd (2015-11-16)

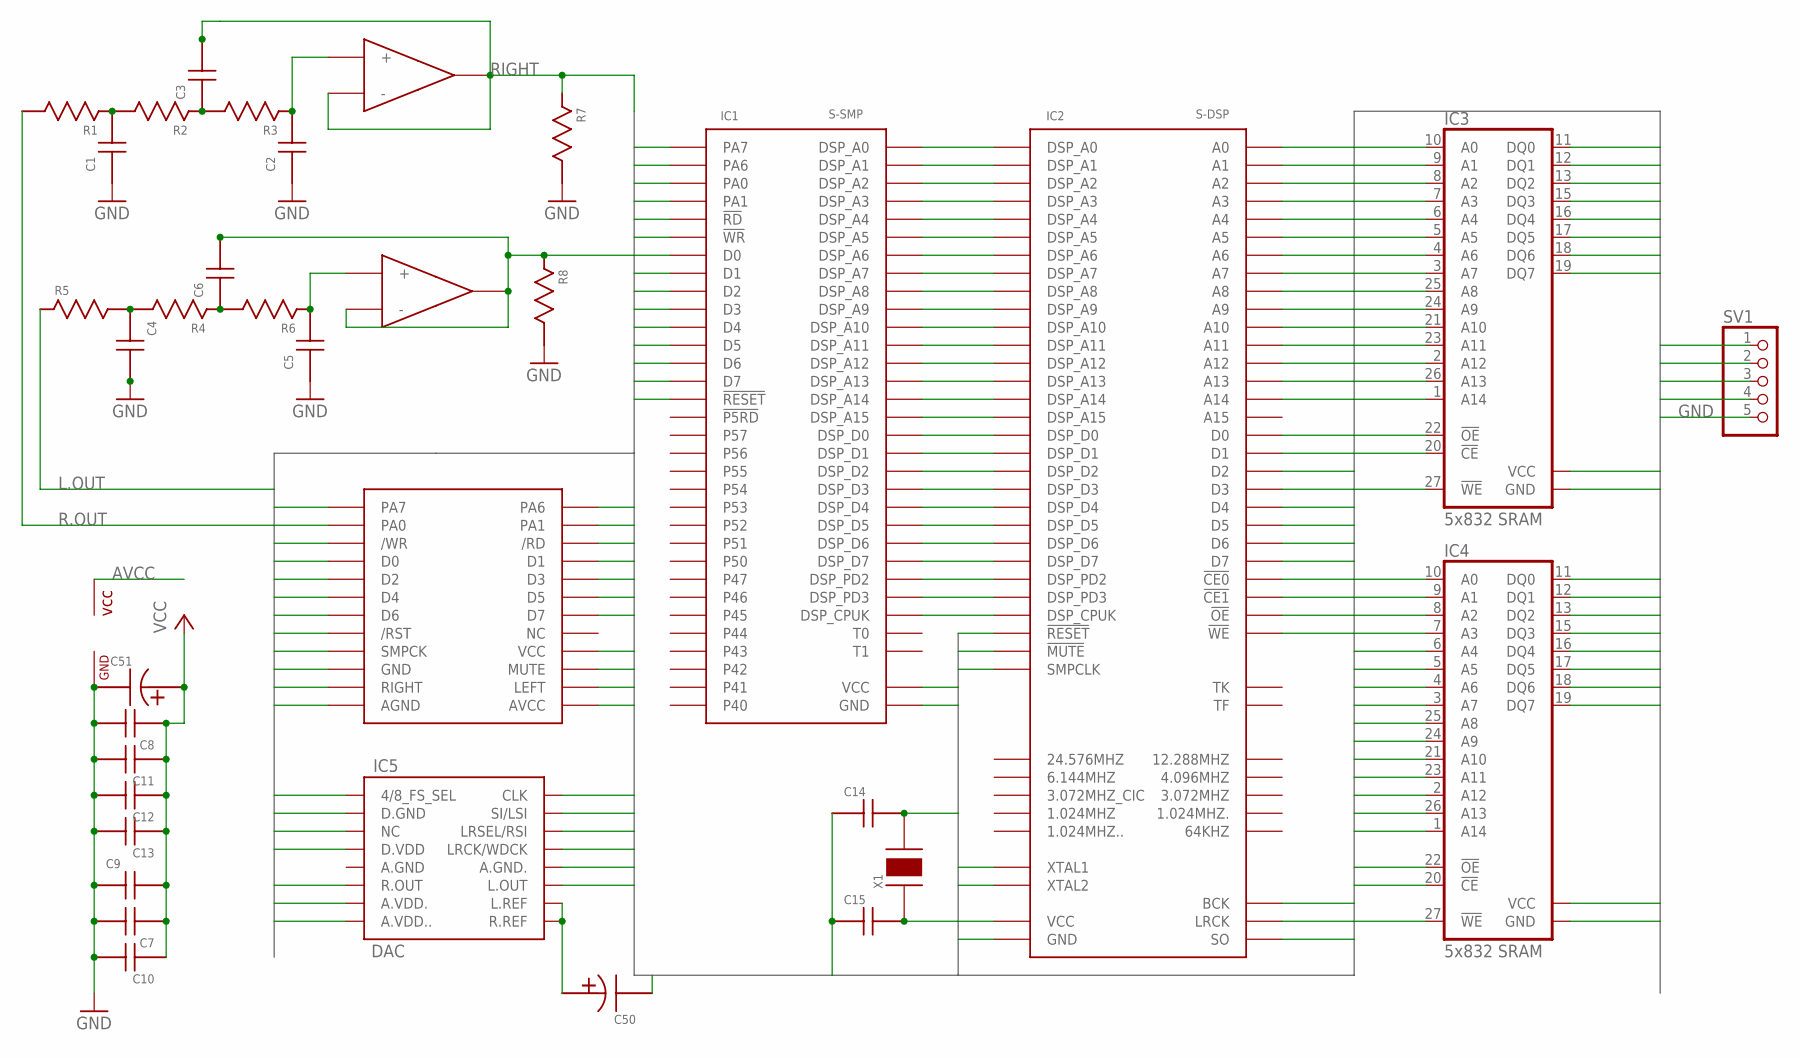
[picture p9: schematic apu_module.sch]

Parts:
C1, C2, C3, C4, C5, C6, C7, C8, C9, C10, C11, C12, C13, C14, C15: C0805
C50, C51: CAPACITOR; TT5D6
E$3: APU
IC1: S-SMP; QFP64_SOT319
IC2: S-DSP; QFP80_SOT318
IC3, IC4: 5x832 SRAM; SO28X
IC5: DAC; SO16W
IC6: LM2904; SO-08
R1, R2, R3, R4, R5, R6, R7, R8: R0805
SV1: PINHD-1X5; 1X05
X1: CRYSTAL; QS

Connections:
!CE0: IC2.28 (!CE0), IC3.20 (!CE)
!CE1: IC2.27 (!CE1), IC4.20 (!CE)
!MUTE: E$3.P$20 (MUTE), IC2.39 (!MUTE)
!OE: IC2.30 (!OE), IC3.22 (!OE), IC4.22 (!OE)
!P_RD: E$3.P$6 (/RD), IC1.46 (!RD)
!P_WR: E$3.P$5 (/WR), IC1.47 (!WR)
!RESET: E$3.P$15 (/RST), IC1.37 (!RESET), IC2.47 (!RESET)
!WE: IC2.36 (!WE), IC3.27 (!WE), IC4.27 (!WE)
A0: IC2.9 (A0), IC3.10 (A0), IC4.10 (A0)
A1: IC2.10 (A1), IC3.9 (A1), IC4.9 (A1)
A2: IC2.11 (A2), IC3.8 (A2), IC4.8 (A2)
A3: IC2.13 (A3), IC3.7 (A3), IC4.7 (A3)
A4: IC2.14 (A4), IC3.6 (A4), IC4.6 (A4)
A5: IC2.15 (A5), IC3.5 (A5), IC4.5 (A5)
A6: IC2.16 (A6), IC3.4 (A6), IC4.4 (A6)
A7: IC2.17 (A7), IC3.3 (A7), IC4.3 (A7)
A8: IC2.34 (A8), IC3.25 (A8), IC4.25 (A8)
A9: IC2.32 (A9), IC3.24 (A9), IC4.24 (A9)
A10: IC2.29 (A10), IC3.21 (A10), IC4.21 (A10)
A11: IC2.31 (A11), IC3.23 (A11), IC4.23 (A11)
A12: IC2.18 (A12), IC3.2 (A12), IC4.2 (A12)
A13: IC2.35 (A13), IC3.26 (A13), IC4.26 (A13)
A14: IC2.19 (A14), IC3.1 (A14), IC4.1 (A14)
A.REF: C50.+, IC5.9 (R.REF), IC5.10 (L.REF)
AVCC: E$3.P$24 (AVCC), IC6.8 (VCC)
BCK: IC2.42 (BCK), IC5.16 (CLK), SV1.4
D0: IC2.8 (D0), IC3.11 (DQ0), IC4.11 (DQ0)
D1: IC2.7 (D1), IC3.12 (DQ1), IC4.12 (DQ1)
D2: IC2.6 (D2), IC3.13 (DQ2), IC4.13 (DQ2)
D3: IC2.22 (D3), IC3.15 (DQ3), IC4.15 (DQ3)
D4: IC2.23 (D4), IC3.16 (DQ4), IC4.16 (DQ4)
D5: IC2.24 (D5), IC3.17 (DQ5), IC4.17 (DQ5)
D6: IC2.25 (D6), IC3.18 (DQ6), IC4.18 (DQ6)
D7: IC2.26 (D7), IC3.19 (DQ7), IC4.19 (DQ7)
DSP_A0: IC1.5 (DSP_A0), IC2.60 (DSP_A0)
DSP_A1: IC1.4 (DSP_A1), IC2.61 (DSP_A1)
DSP_A2: IC1.3 (DSP_A2), IC2.62 (DSP_A2)
DSP_A3: IC1.2 (DSP_A3), IC2.63 (DSP_A3)
DSP_A4: IC1.1 (DSP_A4), IC2.64 (DSP_A4)
DSP_A5: IC1.64 (DSP_A5), IC2.65 (DSP_A5)
DSP_A6: IC1.63 (DSP_A6), IC2.66 (DSP_A6)
DSP_A7: IC1.62 (DSP_A7), IC2.67 (DSP_A7)
DSP_A8: IC1.61 (DSP_A8), IC2.68 (DSP_A8)
DSP_A9: IC1.60 (DSP_A9), IC2.69 (DSP_A9)
DSP_A10: IC1.59 (DSP_A10), IC2.70 (DSP_A10)
DSP_A11: IC1.56 (DSP_A11), IC2.71 (DSP_A11)
DSP_A12: IC1.55 (DSP_A12), IC2.72 (DSP_A12)
DSP_A13: IC1.54 (DSP_A13), IC2.74 (DSP_A13)
DSP_A14: IC1.53 (DSP_A14), IC2.75 (DSP_A14)
DSP_A15: IC1.52 (DSP_A15), IC2.76 (DSP_A15)
DSP_CPUK: IC1.16 (DSP_CPUK), IC2.48 (DSP_CPUK)
DSP_D0: IC1.13 (DSP_D0), IC2.51 (DSP_D0)
DSP_D1: IC1.12 (DSP_D1), IC2.53 (DSP_D1)
DSP_D2: IC1.11 (DSP_D2), IC2.54 (DSP_D2)
DSP_D3: IC1.10 (DSP_D3), IC2.55 (DSP_D3)
DSP_D4: IC1.9 (DSP_D4), IC2.56 (DSP_D4)
DSP_D5: IC1.8 (DSP_D5), IC2.57 (DSP_D5)
DSP_D6: IC1.7 (DSP_D6), IC2.58 (DSP_D6)
DSP_D7: IC1.6 (DSP_D7), IC2.59 (DSP_D7)
DSP_PD2: IC1.15 (DSP_PD2), IC2.49 (DSP_PD2)
DSP_PD3: IC1.14 (DSP_PD3), IC2.50 (DSP_PD3)
GND: C1.1, C2.1, C4.2, C5.1, C7.2, C8.2, C9.1, C10.2, C11.2, C12.2, C13.2, C14.1, C15.1, C50.-, C51.-, E$3.P$19 (GND), E$3.P$23 (AGND), IC1.26 (GND), IC1.58 (GND), IC2.12 (GND), IC2.52 (GND), IC3.14 (GND), IC4.14 (GND), IC5.1 (4/8_FS_SEL), IC5.2 (D.GND), IC5.12 (A.GND.), IC5.14 (LRSEL/RSI), IC6.4 (GND), R7.2, R8.2, SV1.5
L1: C4.1, R4.2, R5.2
L2: C6.1, R4.1, R6.2
L3: C5.2, IC6.5 (+), R6.1
L.OUT: IC5.11 (L.OUT), R5.1
LEFT: C6.2, E$3.P$21 (LEFT), IC6.6 (-), IC6.7 (OUT), R8.1
LRCK: IC2.43 (LRCK), IC5.13 (LRCK/WDCK), SV1.3
PA0: E$3.P$3 (PA0), IC1.49 (PA0)
PA1: E$3.P$4 (PA1), IC1.48 (PA1)
PA6: E$3.P$2 (PA6), IC1.50 (PA6)
PA7: E$3.P$1 (PA7), IC1.51 (PA7)
PD0: E$3.P$7 (D0), IC1.45 (D0)
PD1: E$3.P$8 (D1), IC1.44 (D1)
PD2: E$3.P$9 (D2), IC1.43 (D2)
PD3: E$3.P$10 (D3), IC1.42 (D3)
PD4: E$3.P$11 (D4), IC1.41 (D4)
PD5: E$3.P$12 (D5), IC1.40 (D5)
PD6: E$3.P$13 (D6), IC1.39 (D6)
PD7: E$3.P$14 (D7), IC1.38 (D7)
R1: C1.2, R1.1, R2.2
R2: C3.1, R2.1, R3.2
R3: C2.2, IC6.3 (+), R3.1
R.OUT: IC5.6 (R.OUT), R1.2
RIGHT: C3.2, E$3.P$22 (RIGHT), IC6.1 (OUT), IC6.2 (-), R7.1
SMPCLK: E$3.P$17 (SMPCK), IC2.78 (SMPCLK)
SO: IC2.44 (SO), IC5.15 (SI/LSI), SV1.2
VCC: C7.1, C8.1, C9.2, C10.1, C11.1, C12.1, C13.1, C51.+, E$3.P$18 (VCC), IC1.57 (VCC), IC2.33 (VCC), IC2.73 (VCC), IC3.28 (VCC), IC4.28 (VCC), IC5.3 (NC), IC5.4 (D.VDD), IC5.7 (A.VDD.), IC5.8 (A.VDD..), SV1.1
XTAL1: C15.2, IC2.45 (XTAL1), X1.1
XTAL2: C14.2, IC2.46 (XTAL2), X1.2

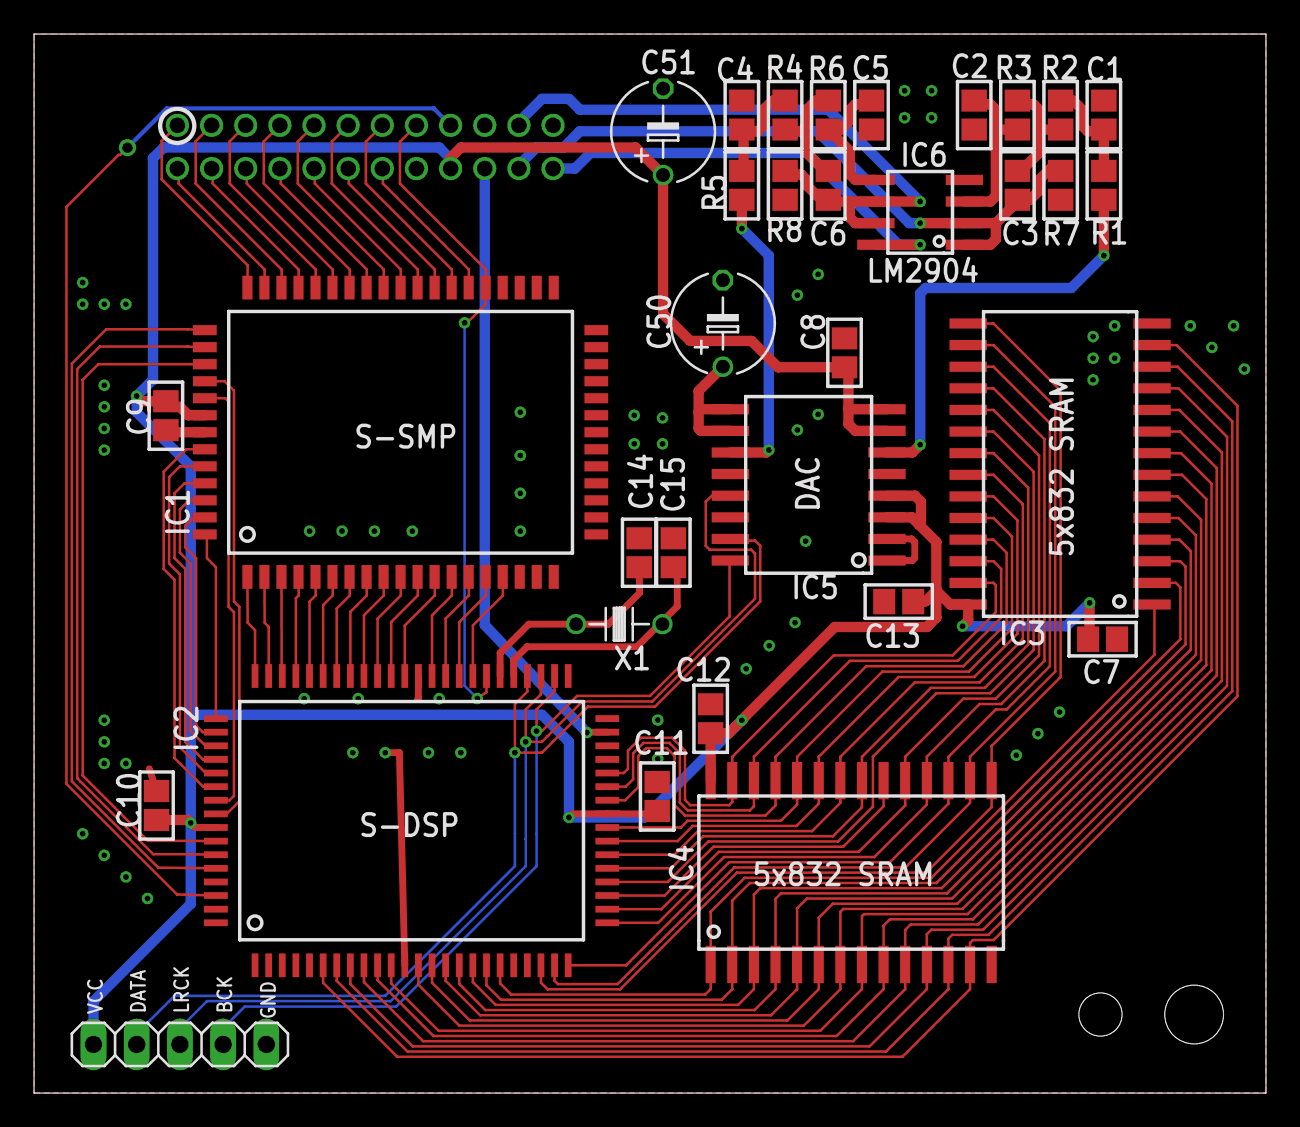
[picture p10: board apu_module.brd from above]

Board: 2 copper layers, 72.4 x 62.2 mm, 34 parts (1 on the bottom side), 90 nets.

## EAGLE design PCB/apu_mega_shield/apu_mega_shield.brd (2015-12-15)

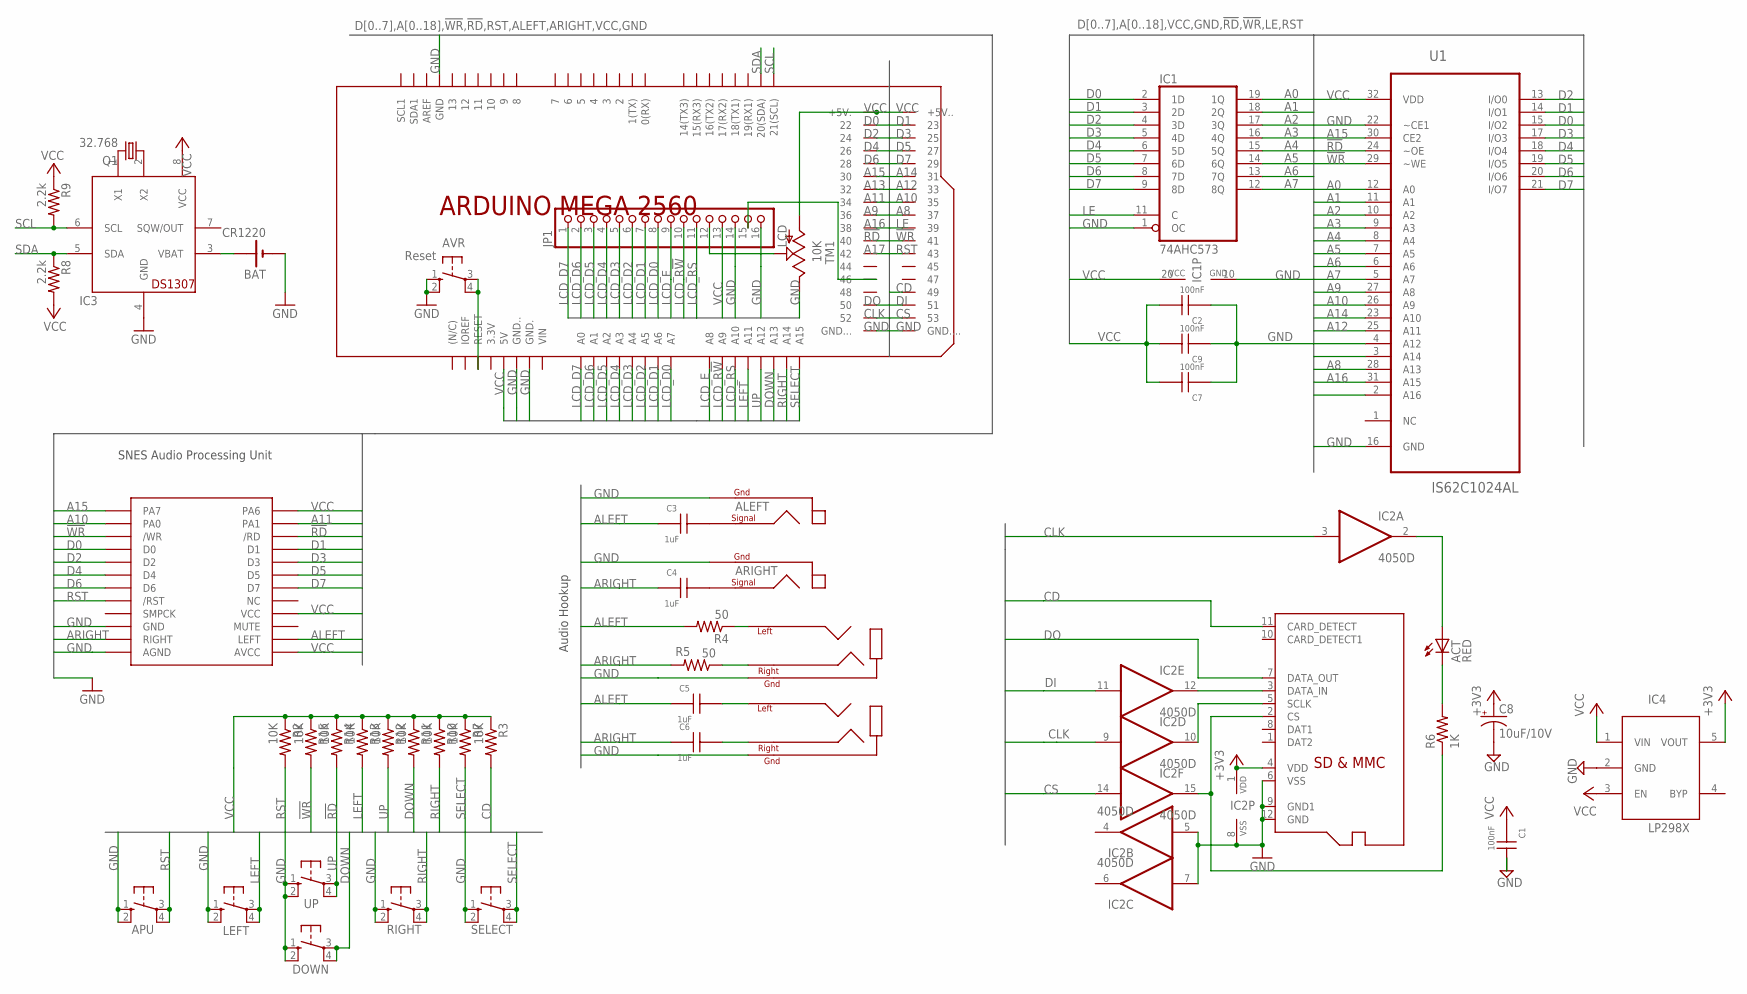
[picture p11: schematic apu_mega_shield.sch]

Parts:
ACT: RED; CHIP-LED0805
APU: Reset; B3F-10XX
AVR: Reset; B3F-10XX
BAT: CR1220; CR1220-SMD
C1, C2, C7, C9: 100nF; C0805
C3, C4, C5, C6: 1uF; C0805
C8: 10uF/10V; A/3216-18R
DOWN: 10-XX; B3F-10XX
IC1: 74AHC573; SO20W
IC2: 4050D; SO16
IC3: DS1307; SO-08
IC4: LP298XS; SOT23-5L
JP1: LCD; 1X16
LEFT: 10-XX; B3F-10XX
Q1: 32.768; SMD
R2, R3, R7, R10, R11, R12, R13, R14, R15: 10K; R0805
R4, R5: 50; R0805
R6: 1K; R0805
R8, R9: 2.2k; R0805
RIGHT: 10-XX; B3F-10XX
SELECT: 10-XX; B3F-10XX
TM1: 10K; CA6H
U1: IS62C1024AL; SOIC127P1412X305-32N
U$1: APU
U$2, U$3: HEADPHONE; SJ1-3533N
U$4, U$5: RCA; RCJ-01X
U$6: ARDUINO_MEGA_2560_LITENO_LABELS; ARDUINO_MEGA2560_LITE_NO_LABELS
UP: 10-XX; B3F-10XX
X1: MICROSDMOLEX; MICROSD-1

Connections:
!RD: R14.2, U1.24 (~OE), U$1.P$6 (/RD), U$6.40
!WR: R15.2, U1.29 (~WE), U$1.P$5 (/WR), U$6.41
+3V3: C8.+, IC2.1 (VDD), IC4.5 (VOUT), X1.4 (VDD)
A0: IC1.19 (1Q), U1.12 (A0)
A1: IC1.18 (2Q), U1.11 (A1)
A2: IC1.17 (3Q), U1.10 (A2)
A3: IC1.16 (4Q), U1.9 (A3)
A4: IC1.15 (5Q), U1.8 (A4)
A5: IC1.14 (6Q), U1.7 (A5)
A6: IC1.13 (7Q), U1.6 (A6)
A7: IC1.12 (8Q), U1.5 (A7)
A8: U1.28 (A13), U$6.37
A9: U1.27 (A8), U$6.36
A10: U1.26 (A9), U$1.P$3 (PA0), U$6.35
A11: U1.3 (A14), U$1.P$4 (PA1), U$6.34
A12: U1.25 (A11), U$6.33
A13: U1.4 (A12), U$6.32
A14: U1.23 (A10), U$6.31
A15: U1.30 (CE2), U$1.P$1 (PA7), U$6.30
A16: U1.31 (A15), U$6.38
A17: U1.2 (A16), U$6.42
ALEFT: C3.1, C5.1, R4.2, U$1.P$22 (LEFT)
ARIGHT: C4.1, C6.1, R5.2, U$1.P$21 (RIGHT)
BUF_CLK: IC2.10 (O), X1.5 (SCLK)
BUF_CS: IC2.15 (O), R6.1, X1.2 (CS)
BUF_DI: IC2.12 (O), X1.3 (DATA_IN)
BUF_LED: ACT.A, IC2.2 (O)
CD: R3.2, U$6.49, X1.11 (CARD_DETECT)
CLK: IC2.3 (I), IC2.9 (I), U$6.52
CS: IC2.14 (I), U$6.53
D0: IC1.2 (1D), U1.15 (I/O2), U$1.P$7 (D0), U$6.22
D1: IC1.3 (2D), U1.14 (I/O1), U$1.P$8 (D1), U$6.23
D2: IC1.4 (3D), U1.13 (I/O0), U$1.P$9 (D2), U$6.24
D3: IC1.5 (4D), U1.17 (I/O3), U$1.P$10 (D3), U$6.25
D4: IC1.6 (5D), U1.18 (I/O4), U$1.P$11 (D4), U$6.26
D5: IC1.7 (6D), U1.19 (I/O5), U$1.P$12 (D5), U$6.27
D6: IC1.8 (7D), U1.20 (I/O6), U$1.P$13 (D6), U$6.28
D7: IC1.9 (8D), U1.21 (I/O7), U$1.P$14 (D7), U$6.29
DI: IC2.11 (I), U$6.51
DO: U$6.50, X1.7 (DATA_OUT)
DOWN: DOWN.3, DOWN.4 (P1), R11.2, U$6.A13
GND: APU.1 (S), APU.2 (S1), AVR.1 (S), AVR.2 (S1), BAT.-, C1.2, C2.1, C7.1, C8.-, C9.1, DOWN.1 (S), DOWN.2 (S1), IC1.1 (OC), IC1.10 (GND), IC2.5 (I), IC2.7 (I), IC2.8 (VSS), IC3.4 (GND), IC4.2 (GND), JP1.14, JP1.16, LEFT.1 (S), LEFT.2 (S1), RIGHT.1 (S), RIGHT.2 (S1), SELECT.1 (S), SELECT.2 (S1), TM1.E, U1.16 (GND), U1.22 (~CE1), U$1.P$19 (GND), U$1.P$23 (AGND), U$2.GND, U$3.GND, U$4.PGND1, U$4.PGND2 (PGND1), U$4.PGND3 (PGND1), U$5.PGND1, U$5.PGND2 (PGND1), U$5.PGND3 (PGND1), U$6.GND, U$6.GND., U$6.GND.., U$6.GND..., U$6.GND...., UP.1 (S), UP.2 (S1), X1.6 (VSS), X1.9 (GND1), X1.12 (GND)
LCD_D0: JP1.8, U$6.A7
LCD_D1: JP1.7, U$6.A6
LCD_D2: JP1.6, U$6.A5
LCD_D3: JP1.5, U$6.A4
LCD_D4: JP1.4, U$6.A3
LCD_D5: JP1.3, U$6.A2
LCD_D6: JP1.2, U$6.A1
LCD_D7: JP1.1, U$6.A0
LCD_E: JP1.9, U$6.A8
LCD_R!W: JP1.10, U$6.A9
LCD_RS: JP1.11, U$6.A10
LE: IC1.11 (C), U$6.39
LEFT: LEFT.3, LEFT.4 (P1), R13.2, U$6.A11
unnamed: AVR.3, AVR.4 (P1), U$6.RESET
unnamed: C3.2, U$4.PSIG
unnamed: C4.2, U$5.PSIG
unnamed: C5.2, U$3.LEFT
unnamed: C6.2, U$3.RIGHT
unnamed: R4.1, U$2.LEFT
unnamed: R5.1, U$2.RIGHT
unnamed: ACT.C, R6.2
unnamed: JP1.12, TM1.S
unnamed: JP1.15, U$6.46
unnamed: BAT.+$1 (+), BAT.+$2 (+), IC3.3 (VBAT)
unnamed: IC3.1 (X1), Q1.2
unnamed: IC3.2 (X2), Q1.1
RIGHT: R10.2, RIGHT.3, RIGHT.4 (P1), U$6.A14
RST: APU.3, APU.4 (P1), R2.2, U$1.P$15 (/RST), U$6.43
SCL: IC3.6 (SCL), R9.2, U$6.21 (21(SCL))
SDA: IC3.5 (SDA), R8.1, U$6.20 (20(SDA))
SELECT: R7.2, SELECT.3, SELECT.4 (P1), U$6.A15
UP: R12.2, U$6.A12, UP.3, UP.4 (P1)
VCC: C1.1, C2.2, C7.2, C9.2, IC1.20 (VCC), IC3.8 (VCC), IC4.1 (VIN), IC4.3 (EN), JP1.13, R2.1, R3.1, R7.1, R8.2, R9.1, R10.1, R11.1, R12.1, R13.1, R14.1, R15.1, TM1.A, U1.32 (VDD), U$1.P$2 (PA6), U$1.P$18 (VCC), U$1.P$24 (AVCC), U$6.5V, U$6.5V. (+5V.), U$6.5V.. (+5V..)

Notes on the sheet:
SNES Audio Processing Unit
Audio Hookup

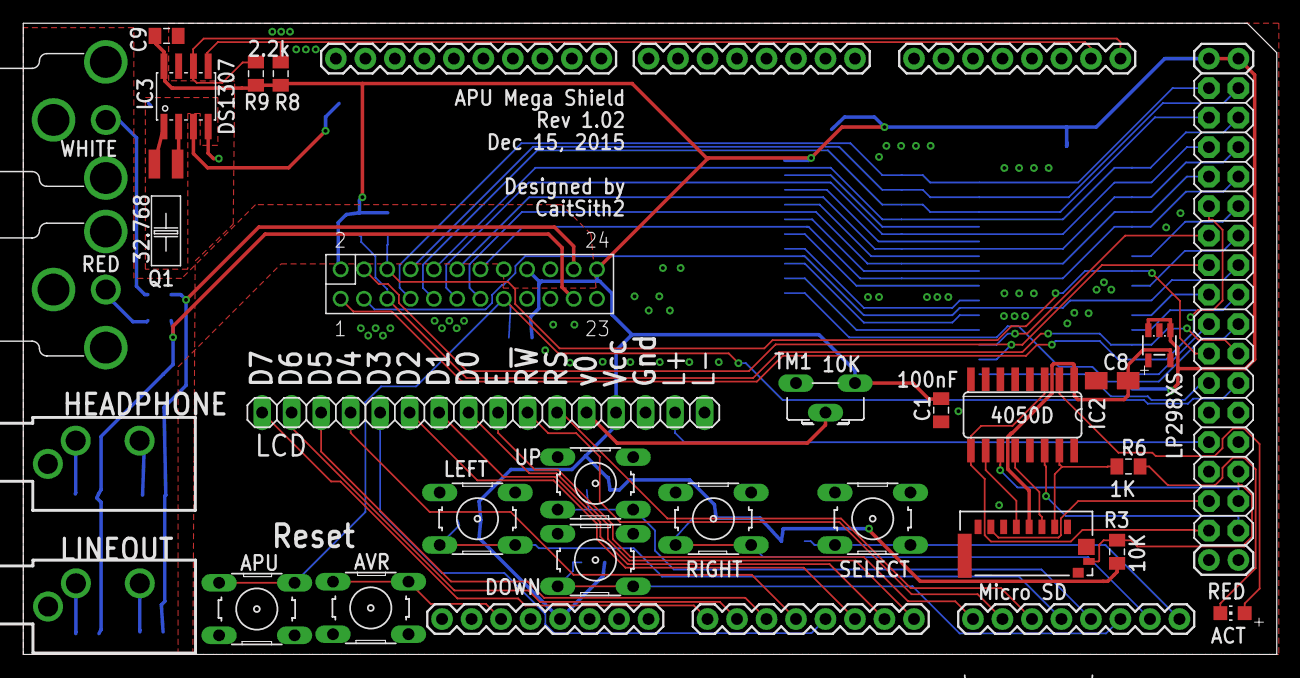
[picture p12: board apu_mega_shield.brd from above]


Board: 2 copper layers, 108.0 x 54.4 mm, 47 parts (19 on the bottom side), 75 nets.

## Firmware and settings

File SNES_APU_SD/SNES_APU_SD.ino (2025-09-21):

/****
   SHVC-SOUND Arduino Player by emu_kidid in 2015
   based on code by CaitSith2

   Loads SPC tracks from SD to the SHVC-SOUND (aka SNES APU)
*/


#include <Firmata.h>
#include <EEPROM.h>
#include "APU.h"
APU apu(APU_TYPE_XMEM);

#ifdef ARDUINO_MEGA
#include <SPI.h>
#include <SdFat.h>
SdFat SD;
#include "LCD.h"
#include <Wire.h>
#include "RTClib.h"
#include "spc_struct.h"

void handleLCD(bool force_refresh = false);
void GetFile(bool print_info = false, bool rewind_dir = true, bool update_lcd = true);
void GetNextFile(bool print_info = false);
void GetPrevFile(bool print_info = false);
void PlaySPC(int SD_mode = 1);

LiquidCrystal lcd;
RTC_DS1307 rtc;

File spcFile;
File root;

#define MAX_FILE_DEPTH 20
int filedepth = 0;
File files[MAX_FILE_DEPTH];
int filecounts[MAX_FILE_DEPTH];
int filecurrent[MAX_FILE_DEPTH];
int rowlen[2];
unsigned char rtc_found = 1;
unsigned char is_spc2;
unsigned short spc2_total_songs;
unsigned short songnum  __attribute__ ((section (".noinit")));
bool debug_print = false;
spc_idx6_table tags  __attribute__ ((section (".noinit")));
bool auto_play;
u32 play_time, total_time;
int auto_play_start;

int song_depth=-1;
int song_current[MAX_FILE_DEPTH];
bool file_changed = false;
bool just_uploaded = false;

static unsigned char boot_code[] =
{
  0x8F, 0x00, 0x00, //      Mov [0], #byte_0
  0x8F, 0x00, 0x01, //      Mov [1], #byte_1
  0x8F, 0xB0, 0xF1, //      Mov [0F1h], #0B0h   ;Clear the IO ports
  0xCD, 0x53,       //      Mov X, #Ack_byte
  0xD8, 0xF4,       //      Mov [0F4h], X

  0xE4, 0xF4,       //IN0:  Mov A, [0F4h]
  0x68, 0x00,       //      Cmp A, #IO_Byte_0
  0xD0, 0xFA,       //      Bne IN0

  0xE4, 0xF7,       //IN3:  Mov A, [0F7h]
  0x68, 0x00,       //      Cmp A, #IO_Byte_3
  0xD0, 0xFA,       //      Bne IN3

  0x8F, 0x31, 0xF1, //      Mov [0F1h], #ctrl_byte

  0x8F, 0x6C, 0xF2, //      Mov [0F2h], 6Ch
  0x8F, 0x00, 0xF3, //      Mov [0F3h], #echo_control_byte
  0x8F, 0x4C, 0xF2, //      Mov [0F2h], 4Ch
  0x8F, 0x00, 0xF3, //      Mov [0F3h], #key_on_byte
  0x8F, 0x7F, 0xF2, //      Mov [0F2h], #dsp_control_register_byte
  0xAE,             //      Pop A
  0xCE,             //      Pop X
  0xEE,             //      Pop Y
  0x7F,             //      RetI
} ;
#endif

bool dataModeText = false;

FILE serial_stdout;

static unsigned char DSPdata[] =
{ //For loading the 128 byte DSP ram. DO NOT CHANGE.
  0xC4, 0xF2,       //START:  Mov [0F2h], A
  0x64, 0xF4,       //LOOP:   Cmp A, [0F4h]
  0xD0, 0xFC,       //        Bne LOOP
  0xFA, 0xF5, 0xF3, //        Mov [0F3h], [0F5h]
  0xC4, 0xF4,       //        Mov [0F4h], A
  0xBC,             //        Inc A
  0x10, 0xF2,       //        Bpl START

  0x8F, 0xFF, 0xFC, //      Mov [0FCh], #timer_2
  0x8F, 0xFF, 0xFB, //      Mov [0FBh], #timer_1
  0x8F, 0x4F, 0xFA, //      Mov [0FAh], #timer_0

  0xCD, 0xF5,       //      Mov X, #stack_pointer
  0xBD,             //      Mov SP, X

  0x2F, 0xAB,       //        Bra 0FFC9h  ;Right when IPL puts AA-BB on the IO ports and waits for CC.
};

// Function that printf and related will use to print
int serial_putchar(char c, FILE* f) {
  if (c == '\n') serial_putchar('\r', f);
  return Serial.write(c) == 1 ? 0 : 1;
}

/*
   PRESCALER of 0 = 16Mhz Clock
   PRESCALER of 1 = 8Mhz Clock
   PRESCALER of 2 = 4Mhz Clock //Couldn't operate my PC interface any slower than this.
   PRESCALER of 3 = 2Mhz Clock
   PRESCALER of 4 = 1Mhz Clock //Baud rates 230400 and 250000 no longer possible
   PRESCALER of 5 = 500Khz Clock //Baud rate 115200 no longer possible.
*/

#define PRESCALER 0
void SetupPrescaler(int prescaler)
{
  Serial.flush(); //Any and all serial output currently in the buffer will be garbage, from
  //the time it takes to change the prescaler till the time serial begins again.
  //As such, we Have to wait till ALL serial has been output before we change the pre-scaler.

  uint32_t baud_rate = 250000 << prescaler;  //Bacuase we are slowing the clock down
  //250000 baud at prescaler 1 actually means 125000 baud.  We have to compensate for this.

  noInterrupts();  //Since the following writes are timing sensitve, disable interrupts.
  CLKPR = 0x80;  //Write CLKPCE = 1 and CLKPSx = 0
  CLKPR = prescaler;  //Write CLKPCE = 0 and CLKPSx with desired value
  interrupts();
  delay(5);
  Serial.begin(baud_rate);  //Now we begin serial. :)
}


void setup()
{
  Serial.begin(250000);
  SetupPrescaler(PRESCALER);

  // Set up stdout
  fdev_setup_stream(&serial_stdout, serial_putchar, NULL, _FDEV_SETUP_WRITE);
  stdout = &serial_stdout;

  Serial.println(F("SHVC-SOUND Arduino Player v0.1"));
#ifdef ARDUINO_MEGA
  clear_current_song();
  lcd.begin(16, 2);

  Serial.print(F("Initializing RTC... "));
  if (! rtc.begin()) {
    Serial.println(F("Couldn't find RTC :("));
    rtc_found = 0;
  }
  else
  {
    if (! rtc.isrunning()) {
      Serial.println(F("RTC is NOT running!, Setting it now."));
      // following line sets the RTC to the date & time this sketch was compiled
      rtc.adjust(DateTime(F(__DATE__), F(__TIME__)));
      // This line sets the RTC with an explicit date & time, for example to set
      // January 21, 2014 at 3am you would call:
      // rtc.adjust(DateTime(2014, 1, 21, 3, 0, 0));
    }
    else
    {
      Serial.println(F("RTC is running! :)"));
      readButtons();
      if (IsButtonPressed(LEFT) && IsButtonPressed(RIGHT))
      {
        rtc.adjust(DateTime(F(__DATE__), F(__TIME__)));
        Serial.println(F("Forcing an RTC Adjustment!"));
        while (IsButtonPressed(LEFT) || IsButtonPressed(RIGHT));
      }
    }
  }

  delay(250);
  if (Serial.available()) return;

  dataModeText = true;
  Serial.print(F("Initializing SD card... "));

  if (!SD.begin(53)) {
    Serial.print(F("initialization failed!\n"));
    return;
  }
  Serial.print(F("initialization done.\n"));

  root = SD.open("spc/");
  if (!root)
  {
    Serial.print(F("Could not open root directory.\n"));
    Serial.print(F("Put all spc files/folders in directory named \"spc\""));
    return;
  }
  filedepth = 0;
  CountFiles();
  Serial.println(F("----START OF DIRECTORY LISTING----"));
  for (filecurrent[filedepth] = 0; filecurrent[filedepth] < filecounts[filedepth]; filecurrent[filedepth]++)
    GetFile(true, !filecurrent[filedepth], false);
  Serial.println(F("----END OF DIRECTORY LISTING----"));
  GetFile();
#endif
}

#ifdef ARDUINO_MEGA

int len(char *string, int maxlen)
{
  for (int i = 0; i < maxlen; i++)
    if (string[i] == 0)
      return i;
  return maxlen;
}

#define LCD_DISPLAY_MODE_NORMAL 0
#define LCD_DISPLAY_MODE_DATETIME 1

#define LCD_SCROLL_DELAY_LONG 128
#define LCD_SCROLL_DELAY_SHORT 8
int lcd_delay[2] = {LCD_SCROLL_DELAY_LONG,LCD_SCROLL_DELAY_LONG};
int lcd_pos[2] = {0,0};
#define LINE_0_LEN 448
#define LINE_1_LEN 64
int line_len_max[] = {LINE_0_LEN, LINE_1_LEN};
char lcd_line_0[LINE_0_LEN];
char lcd_line_1[LINE_1_LEN];
char* lcd_buffer[] = {lcd_line_0, lcd_line_1};
char file_index[5];
void refreshLCD()
{
  rowlen[0] = lcd_buffer[0][0] = rowlen[1] = lcd_buffer[1][0] = 0;
  lcd_pos[0] = lcd_pos[1] = 0;
  lcd_delay[0] = lcd_delay[1] = LCD_SCROLL_DELAY_LONG;

  if (files[filedepth])
  {
    files[filedepth].getName(lcd_buffer[0], line_len_max[0]);
    rowlen[0] = len(lcd_buffer[0], line_len_max[0]);
    if (files[filedepth].isDirectory())
    {
      lcd_buffer[0][rowlen[0]++] = '/';
      lcd_buffer[0][rowlen[0]] = 0;
      switch_lcd_display_mode(LCD_DISPLAY_MODE_DATETIME);
    }
    else
    {
      if (IsSPC())
      {
        switch_lcd_display_mode(LCD_DISPLAY_MODE_NORMAL);
        spcFile = files[filedepth];
        readSPCRegion((unsigned char*)lcd_buffer[1], 0x2EL, 0x20);
        rowlen[1] = len(lcd_buffer[1], line_len_max[1]);
      }
      else
        switch_lcd_display_mode(LCD_DISPLAY_MODE_DATETIME);
    }
  }
}

void CountFiles()
{
  File dir = (filedepth == 0) ? root : files[filedepth - 1];
  filecurrent[filedepth] = -1;
  filecounts[filedepth] = 0;

  while (true)
  {
    files[filedepth] = dir.openNextFile();
    if (files[filedepth])
    {
      filecounts[filedepth]++;
      filecurrent[filedepth]++;
      files[filedepth].close();
    }
    else
    {
      return;
    }
  }
}

void GetFile(bool print_info, bool rewind_dir, bool update_lcd)
{
  File dir = (filedepth == 0) ? root : files[filedepth - 1];
  if (rewind_dir)
  {
    if (filecurrent[filedepth] < 0)
      filecurrent[filedepth] += filecounts[filedepth];
    if (filecurrent[filedepth] == filecounts[filedepth])
      filecurrent[filedepth] = 0;

    dir.rewindDirectory();
    for (int i = 0; i <= filecurrent[filedepth]; i++)
    {
      if (files[filedepth])
        files[filedepth].close();
      files[filedepth] = dir.openNextFile();
    }
  }
  else
  {
    if (files[filedepth])
      files[filedepth].close();
    files[filedepth] = dir.openNextFile();
  }
  if (filedepth == 0)
    root = dir;
  else
    files[filedepth - 1] = dir;

  refreshLCD();
  if (print_info)
  {
    Serial.print('[');
    sprintf(file_index, (filecounts[filedepth] > 256 ? "%04X" : "%02X"), filecurrent[filedepth]);
    Serial.print(file_index);
    Serial.print(F("]|"));
    Serial.print(lcd_buffer[0]);
    if (IsSPC())
    {
      Serial.print(F(" - Track Name: ")); Serial.print(lcd_buffer[1]);
    }
    Serial.println();
  }
  if (update_lcd)
    handleLCD(true);
}

void GetNextFile(bool print_info)
{
  filecurrent[filedepth]++;
  GetFile(print_info, filecurrent[filedepth] >= filecounts[filedepth]);
}

void GetPrevFile(bool print_info)
{
  filecurrent[filedepth]--;
  GetFile(print_info);
}

void EnterDirectory()
{
  if (files[filedepth].isDirectory())
  {
    filedepth++;
    if(filedepth <= MAX_FILE_DEPTH)
    {
      CountFiles();
      GetNextFile();
    }
    else
    {
      filedepth--;
      Serial.println("Error: Max Directory depth reached.");
    }
  }
}

void LeaveDirectory()
{
  filedepth--;
  GetFile(dataModeText);
}

#endif



void APU_StartWrite(unsigned short address, unsigned char *data, int len)
{
  int i;
  uint8_t rdata;
  apu.reset();

  while (apu.read(0) != 0xAA);
  while (apu.read(1) != 0xBB);


  apu.write(3, address >> 8);
  apu.write(2, address & 0xFF);
  apu.write(1, 1);
  apu.write(0, 0xCC);
  while (apu.read(0) != 0xCC);

  for (i = 0; i < len; i++)
  {
    apu.write(1, data[i]);
    apu.write(0, i & 0xFF);
    while (apu.read(0) != (i & 0xFF));
  }
}

void APU_Wait(unsigned char address, unsigned char data)
{
  while (apu.read(address) != data);
}

int APU_StartSPC700(unsigned char *dspdata, unsigned char *spcdata, int SD_mode = 1)
{
  //'G'
  int port0state = 0, i = 0, j = 0;

  DSPdata[15] = spcdata[0xFC];  //Helps to shrink the bootcode by 30 bytes.
  DSPdata[18] = spcdata[0xFB];  //bootcode was formerly 77 bytes long.
  DSPdata[21] = spcdata[0xFA];
  DSPdata[24] = spcdata[0xFF];

  if (SD_mode) Serial.print(F("Uploading DSP Register Loader...."));
  //Upload the DSP register, and the first page of SPC data at serial port speed.
  APU_StartWrite(0x0002, DSPdata, sizeof(DSPdata));
  apu.write(2, 0x02);
  apu.write(3, 0x00);
  apu.write(1, 0x00);
  apu.write(0, sizeof(DSPdata) + 1);
  while (apu.read(0) != (sizeof(DSPdata) + 1));
  if (SD_mode)
  {
    Serial.println(F("Done"));
    Serial.print(F("Uploading dspdata...."));
  }
  // Send dspdata[0] to dspdata[127]
  for (i = 0; i < 128; i++)
  {
    if (i == 0x4C)
      apu.write(1, 0x00);
    else if (i == 0x6C)
      apu.write(1, 0x60);
    else
      apu.write(1, dspdata[i]);
    apu.write(0, port0state);
    j = 0;
    if (i < 127)
      while (apu.read(0) != port0state)
      {
        if (j++ > 512)
          return 1;
      }
    port0state++;
  }
  j = 0;
  while (apu.read(0) != 0xAA)
  {
    if (j++ > 512)
      return false;
  }
  if (SD_mode)
  {
    Serial.println(F("Done"));
    Serial.print(F("Uploading spcdata"));
  }
  port0state = 0;
  apu.write(2, 0x02);
  apu.write(3, 0x00);
  apu.write(1, 0x01);
  apu.write(0, 0xCC);
  j = 0;
  while (apu.read(0) != 0xCC)
  {
    if (j++ > 512)
      return 2;
  }
  // Send spcdata[0] to spcdata[255]
  for (i = 0; i < 256; i++)
  {
    if (i < 2)
      continue;
    if (i >= 0xF0)
      continue;
    apu.write(1, spcdata[i]);
    apu.write(0, port0state);
    j = 0;
    while (apu.read(0) != port0state)
    {
      if (j++ > 512)
        return 3;
    }
    port0state++;
  }
  return 0;
}

bool WriteByteToAPUAndWaitForState(unsigned char data, unsigned char state) {
  int i = 4096;
  apu.write(1, data);
  apu.write(0, state);
  while (apu.read(0) != state)
  {
    i--;
    if (i == 0)
      return false;
  }
  return true;
}

// APU_WaitIoPort
int APU_WaitIoPort(uint8_t address, uint8_t data, int timeout)
{
  int i = 0;
  while ((apu.read(address) != data) && (i < timeout)) i++;
  if (i < timeout)
    return 0;
  return 1;
}

#ifdef ARDUINO_MEGA
// Reads raw from a SPC file
unsigned char readSPC(long addr)
{
  spcFile.seek(addr);
  return spcFile.read();
}

// Reads raw from the SPC File
void readSPCRegion(unsigned char *buf, long addr, unsigned short len)
{
  spcFile.seek(addr);
  spcFile.read(buf, len);
}

// Reads from the spcdata region of a file (adjusts for header)
unsigned char readSPCData(unsigned short addr)
{
  if (spcFile.position() != (unsigned long)(addr + 0x100)) {
    if (!spcFile.seek((unsigned long)(addr + 0x100))) { // Adjust for SPC Header
      Serial.print(F("Seek failed at addr ")); printf("%08X\n", (unsigned long)(addr + 0x100));
      while (1);
    }
  }
  return spcFile.read();
}

// Clears a buffer (memset)
void clearBuffer(unsigned char *buf, long len)
{
  int i = 0;
  for (i = 0; i < len; i++) {
    buf[i] = 0;
  }
}


void get_spc2_page(unsigned char *buf, unsigned short song, unsigned char page, unsigned short count = 256)
{
  unsigned long spc2_offset = 16 + ((unsigned long)song * 1024);
  unsigned long spcram_start = 16 + ((unsigned long)spc2_total_songs * 1024);
  unsigned short page_number = readSPC(spc2_offset + (page * 2)) | (readSPC(spc2_offset + (page * 2) + 1) << 8);
  spcram_start += page_number * 256;
  readSPCRegion(buf, spcram_start, count);
}

unsigned short bootcode_offset;
void ReadSPCFromSD()
{
  bootcode_offset = 0;
  digitalWrite(SRAM_PIN_1, LOW);
  digitalWrite(SRAM_PIN_0, LOW);
  readSPCRegion((unsigned char*)&_SFR_MEM8(0x8000), 0x100, 0x8000);
  digitalWrite(SRAM_PIN_0, HIGH);
  readSPCRegion((unsigned char*)&_SFR_MEM8(0x8000), 0x8100, 0x8000);
  digitalWrite(SRAM_PIN_1, HIGH);
  digitalWrite(SRAM_PIN_0, LOW);
  readSPCRegion((unsigned char*)&_SFR_MEM8(0x8000), 0x000, 0x100);
  readSPCRegion((unsigned char*)&_SFR_MEM8(0x8100), 0x10100, 0x100);
  _SFR_MEM8(0x8200) = 0;  //Fixes a bug caused by loading a no extended tag spc, after loading an spc with extended tags.
  readSPCRegion((unsigned char*)&_SFR_MEM8(0x8200), 0x10200, 0x7E00);
  ProcessSPCTags();
  spcFile.getName(tags.spc_filename, MAX_SPC_FILENAME);
}

void ReadSPC2FromSD(unsigned short song)
{
  unsigned long spc2_offset = 16 + ((unsigned long)song * 1024);
  unsigned long spc2_page_offset = 0;
  unsigned short i, j;

  clearBuffer((u8*)&tags, sizeof(spc_idx6_table));

  digitalWrite(SRAM_PIN_1, HIGH);
  digitalWrite(SRAM_PIN_0, LOW);

  //Read the registers.
  for (i = 0; i < 7; i++)
    _SFR_MEM8(0x8025 + i) = readSPC(spc2_offset + 704 + i);

  //Read DSP registers
  readSPCRegion((unsigned char*)&_SFR_MEM8(0x8100), spc2_offset + 512, 128);

  //Read IPL region
  readSPCRegion((unsigned char*)&_SFR_MEM8(0x81C0), spc2_offset + 640, 64);

  //Read SPC Ram
  digitalWrite(SRAM_PIN_1, LOW);
  for (i = 0; i < 128; i++)
    get_spc2_page((unsigned char*)_SFR_MEM8(0x8000 + (i << 8)), song, i);

  digitalWrite(SRAM_PIN_0, HIGH);
  for (i = 0; i < 128; i++)
    get_spc2_page((unsigned char*)_SFR_MEM8(0x8000 + (i << 8)), song, i + 0x80);

  bootcode_offset = readSPC(spc2_offset + 734) | (readSPC(spc2_offset + 735) << 8);

  //Process tags
  readSPCRegion((u8*)&tags.date, spc2_offset + 712, 4);
  readSPCRegion((u8*)&tags.intro_len, spc2_offset + 716, 32);
  readSPCRegion((u8*)&tags.fade_len, spc2_offset + 720, 32);
  readSPCRegion((u8*)&tags.emulator, spc2_offset + 728, 32);
  readSPCRegion((u8*)&tags.ost_disc, spc2_offset + 729, 32);
  readSPCRegion((u8*)&tags.ost_track, spc2_offset + 730, 32);
  readSPCRegion((u8*)&tags.copyright, spc2_offset + 732, 32);
  readSPCRegion((u8*)&tags.boot_code, spc2_offset + 734, 32);
  readSPCRegion((u8*)&tags.song_title, spc2_offset + 768, 32);
  readSPCRegion((u8*)&tags.game_title, spc2_offset + 800, 32);
  readSPCRegion((u8*)&tags.song_artist, spc2_offset + 832, 32);
  readSPCRegion((u8*)&tags.dumper_name, spc2_offset + 864, 32);
  readSPCRegion((u8*)&tags.comments, spc2_offset + 896, 32);
  readSPCRegion((u8*)&tags.ost_title, spc2_offset + 928, 32);
  readSPCRegion((u8*)&tags.pub_name, spc2_offset + 960, 32);
  readSPCRegion((u8*)&tags.spc_filename, spc2_offset + 992, 28);
  unsigned long extended;
  readSPCRegion((u8*)&extended, spc2_offset + 1020, 4);
  if (extended)
  {
    u8 buf[257];
    bool seen[10] = {false, false, false, false, false, false, false, false, false, false};

    do
    {
      readSPCRegion(buf, extended, 257);
      extended += 2;
      extended += buf[1];
      if (buf[0] > 9) break; //Invalid tag data, as per spc2 file specificaiton v1.3.
      if (!seen[buf[0]])
      {
        switch (buf[0])
        {
          case 1:
            memcpy((u8*)&tags.song_title[32], &buf[2], MAX_SONG_TITLE - 32);
            tags.song_title[MAX_SONG_TITLE - 1] = 0;
            break;
          case 2:
            memcpy((u8*)&tags.game_title[32], &buf[2], MAX_GAME_TITLE - 32);
            break;
          case 3:
            memcpy((u8*)&tags.song_artist[32], &buf[2], MAX_SONG_ARTIST - 32);
            break;
          case 4:
            memcpy((u8*)&tags.dumper_name[32], &buf[2], MAX_DUMPER_NAME - 32);
            break;
          case 5:
            memcpy((u8*)&tags.comments[32], &buf[2], MAX_COMMENTS - 32);
            break;
          case 6:
            memcpy((u8*)&tags.ost_title[32], &buf[2], MAX_OST_TITLE - 32);
            break;
          case 7:
            memcpy((u8*)&tags.pub_name[32], &buf[2], MAX_PUB_NAME - 32);
            break;
          case 8:
            memcpy((u8*)&tags.spc_filename[28], &buf[2], MAX_SPC_FILENAME - 32);
            break;
        }
        seen[buf[0]] = true;
      }
    } while (buf[0]);
  }

}

bool IsSPC()
{
  IsSPC(files[filedepth]);
}

bool IsSPC(File file)
{
  if (file.isDirectory()) return false;
  if (file.size() < 66048) return false;
  if (file.size() > 131592L) return false;
  u8 buf[0x1E];
  file.seek(0);
  file.read(buf, 0x1D);
  buf[0x1D] = 0;
  return !strncmp((char*)&buf[0], "SNES-SPC700 Sound File Data v", 0x1D);
}


void spc_push(unsigned char *sp, unsigned char data, const __FlashStringHelper *ifsh)
{
  if (debug_print) {
    Serial.print(ifsh);
    printf("%04X=%02X\n", 0x100 + sp[0], data);
  }
  _SFR_MEM8(0x8000 + 0x100 + sp[0]) = data;
  sp[0]--;
}

void LoadAndPlaySPC()
{
  ReadSPCFromSD();
  PlaySPC();
}
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
void loop() //The main loop.  Define various subroutines, and call them here. :)
{
  unsigned long loop_start, loop_end;
  loop_start = millis();
  ProcessCommandFromSerial();
#ifdef ARDUINO_MEGA
  handleButtons();
  handleLCD();
  loop_end = millis();
  loop_end -= loop_start;

  if (just_uploaded)
  {
    just_uploaded = false;
    if (!auto_play)
      play_time = 0;
    return;
  }

  play_time += loop_end;
  if (auto_play)
  {
    if(play_time >= total_time)
    {
      if(tags.spc_filename[0])
      {
        do
        {
          GetNextFile(true);
        } while (!IsSPC() && (auto_play_start < filecurrent[filedepth]));
        if (auto_play_start >= filecurrent[filedepth])
        {
          auto_play = false;
          clear_current_song();
          apu.reset();
          Serial.println(F("Last SPC file in current directory finished playing"));
          return;
        }
        LoadAndPlaySPC();
      }
      else if (newSPCinRAM)
      {
        PlaySPC();
        newSPCinRAM = false;
        Serial.println(F("Ready for next SPC"));
      }
      else
      {
        auto_play = false;
        clear_current_song();
        apu.reset();
        Serial.println(F("SPC in ram is done playing."));
      }
    }
  }
#endif
}

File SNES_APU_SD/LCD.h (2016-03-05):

#ifndef LiquidCrystal_h
#define LiquidCrystal_h
#if (defined(__AVR_ATmega2560__) || defined(__AVR_ATmega1280__))

#include <inttypes.h>
#include "Print.h"

// commands
#define LCD_CLEARDISPLAY 0x01
#define LCD_RETURNHOME 0x02
#define LCD_ENTRYMODESET 0x04
#define LCD_DISPLAYCONTROL 0x08
#define LCD_CURSORSHIFT 0x10
#define LCD_FUNCTIONSET 0x20
#define LCD_SETCGRAMADDR 0x40
#define LCD_SETDDRAMADDR 0x80

// flags for display entry mode
#define LCD_ENTRYRIGHT 0x00
#define LCD_ENTRYLEFT 0x02
#define LCD_ENTRYSHIFTINCREMENT 0x01
#define LCD_ENTRYSHIFTDECREMENT 0x00

// flags for display on/off control
#define LCD_DISPLAYON 0x04
#define LCD_DISPLAYOFF 0x00
#define LCD_CURSORON 0x02
#define LCD_CURSOROFF 0x00
#define LCD_BLINKON 0x01
#define LCD_BLINKOFF 0x00

// flags for display/cursor shift
#define LCD_DISPLAYMOVE 0x08
#define LCD_CURSORMOVE 0x00
#define LCD_MOVERIGHT 0x04
#define LCD_MOVELEFT 0x00

// flags for function set
#define LCD_8BITMODE 0x10
#define LCD_4BITMODE 0x00
#define LCD_2LINE 0x08
#define LCD_1LINE 0x00
#define LCD_5x10DOTS 0x04
#define LCD_5x8DOTS 0x00

// Control line pins
#define LCD_E 0x01
#define LCD_RW 0x02
#define LCD_RS 0x04

class LiquidCrystal : public Print {
public:
  LiquidCrystal();

  void init();
    
  void begin(uint8_t cols, uint8_t rows, uint8_t charsize = LCD_5x8DOTS);

  void clear();
  void home();

  void noDisplay();
  void display();
  void noBlink();
  void blink();
  void noCursor();
  void cursor();
  void scrollDisplayLeft();
  void scrollDisplayRight();
  void leftToRight();
  void rightToLeft();
  void autoscroll();
  void noAutoscroll();

  void setRowOffsets(int row1, int row2, int row3, int row4);
  void createChar(uint8_t, uint8_t[]);
  void setCursor(uint8_t, uint8_t); 
  virtual size_t write(uint8_t);
  void command(uint8_t);
  
  using Print::write;
private:
  void send(uint8_t, uint8_t);
  void write8bits(uint8_t);
  void pulseEnable();

  uint8_t _rs_pin; // LOW: command.  HIGH: character.
  uint8_t _rw_pin; // LOW: write to LCD.  HIGH: read from LCD.
  uint8_t _enable_pin; // activated by a HIGH pulse.
  uint8_t _data_pins[8];

  uint8_t _displayfunction;
  uint8_t _displaycontrol;
  uint8_t _displaymode;

  uint8_t _initialized;

  uint8_t _numlines;
  uint8_t _row_offsets[4];
};

#endif
#endif

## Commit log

2015-10-27 Initial commit (Not yet ready for production.)
    [apu_mega_shield.brd, apu_mega_shield.sch]
2015-10-27 Micro SD card detect pullup resistor added.
    [apu_mega_shield.brd, apu_mega_shield.sch]
2015-10-27 Removed the OR gate reset mechanism, as that pretty much was only used on Arduino / Parallel port hybrid builds.
    [SNES_APU_SD.ino]
2015-10-27 Part list for the Arduino mega apu shield PCB
2015-10-28 Added 3.3v regulator due to Arduino 3.3v line being limited to 50ma. (Micro SD cards can draw up to 100ma while they are being written to.)
    [apu_mega_shield.brd, apu_mega_shield.sch]
2015-10-29 LCD now interfaced using 8-bit mode instead of 4-bit mode.
    [apu_mega_shield.brd, apu_mega_shield.sch]
2015-10-29 115200 baud fallback added for backwards compatibility with legacy arduino sketches.
2015-10-29 Commented some of the code. Reduced the delay from when the string is printed, to when the arduino attempts to load file.spc from the SD card. (2 seconds of every arduino reset is occupied in the ard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
    [SNES_APU_SD.ino]
2015-10-30 Hopefully final PCB design for version 1.0 :)
    [Bill of Materials.csv, apu_mega_shield.brd, apu_mega_shield.sch]
2015-10-30 Changed silkscreen widths. Added gerbers for ordering at places that don't support eagle files directly. :)
    [apu_mega_shield.brd]
2015-10-31 Replaced Capacitors C3,C4,C5,C6 with parts that are a bit cheaper.
    [Bill of Materials.csv]
2015-10-31 Parts list made into csv format.
    [arduino mega apu shield parts list.csv]
2015-10-31 Removed quote marks.
    [Bill of Materials.csv]
2015-10-31 Sketch now works, (in PC mode only), on the standard Arduino formfactor boards.
2015-11-01 Bill of Materials updated with a female header that should be long enough to mate with the long male pins.
    [Bill of Materials.csv, arduino mega apu shield parts list.csv]
2015-11-01 Cleaned up a redundant net connection point.
    [apu_mega_shield.sch]
2015-11-02 minor bug fix for when certain buttons are accidentally double-clicked.
    [SNES_APU_SD.ino]
2015-11-03 Added preliminary spc2 file support. (still hard-coded filename).
    Fixed a minor bug in the bootcode seaching function.
    [APU.h, SNES_APU_SD.ino]
2015-11-08 Commented the boot code and dsp loader blocks with a disassembly. Planning on changing both of them, so that the boot loader block can be made smaller than the 77 bytes it currently is. :)
2015-11-16 PCB design for mounting APU components taken from a revision 2 snes.
    [apu_pcb.brd, apu_pcb.sch]
2015-11-16 Improvements on the pc application
    [apu_pcb.brd]
2015-11-18 All parts that are not buttons or connectors replaced with SMT equivalents. :)
    [apu_mega_shield.brd, apu_mega_shield.sch]
2015-11-19 Integrated APU mega shield
    [apu_mega_shield_integradted.brd, apu_mega_shield_integradted.sch, integrated APU mega shield.xls]
2015-11-19 Forgot a couple of parts
    [integrated APU mega shield.xls]
2015-11-24 R1 removed from PCB. It was supposed to be the current limiting resistor for the LCD backlight, however, the LCD module in use already has a current limiting resistor mounted right on that module.
    [apu_mega_shield.brd, apu_mega_shield.sch, apu_mega_shield_integradted.brd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]
2015-11-25 Tweaked reset button layouts. On the module version of the board, SD card connector and its supporting components moved.
    [apu_mega_shield.brd, apu_mega_shield_integradted.brd]
2015-11-27 Optimized layout a bit more.
    [apu_mega_shield_integradted.brd, apu_mega_shield_integradted.sch]
2015-12-15 Final revisions to the PCB design, hopefully. :)
    [apu_mega_shield.brd, apu_mega_shield.sch, apu_mega_shield_integradted.brd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]
2015-12-23 Reorganize directory structure
    [Bill of Materials.csv, apu_mega_shield.brd, apu_mega_shield.sch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]
2015-12-23 Bill of materials added for hardware SPC player
    [bill of materials.xls]
2015-12-23 schematic sheets used more effectively.
    [apu_standalone.brd, apu_standalone.sch]
2015-12-23 Missed a part out of the BOM
    [bill of materials.xls]
2015-12-23 Change out PTC fuse for better clearance.
    [apu_standalone.brd, apu_standalone.sch]
2015-12-24 minor fix to swapped out component on schematic.
    [apu_standalone.sch]
2016-01-05 - Fix overflow with last SPC block read
    [SNES_APU_SD.ino]
2016-03-07 LCD now shows spc upload progress when an spc is uploading to the APU.
    [apu_standalone.brd, apu_standalone.sch]
2016-03-14 PC Side communications
    Added various commands for a planned total rewrite of the PC side
    client,.
    [apu_standalone.brd, apu_standalone.sch]
2016-03-15 Changed micro-SD holder to push-in-push-out type.
    [apu_standalone.brd, apu_standalone.sch, bill of materials.xls]
2016-03-15 Whoops, wrong microSD holder.
    [bill of materials.xls]
2016-03-25 APU reset after last file in directory is played.
    [SNES_APU_SD.ino]
2016-03-26 Holding reset button no longer exceeds max rated IO line current.
    [APU.cpp]
2016-03-27 fixed legacy arduino compilation once again.
    [APU.cpp, SNES_APU_SD.ino]
2016-04-04 Currently playing song scroller and time remaining.
2016-04-04 APU reset button now has a 470 ohm series resistor to ground.
    [apu_standalone.brd, apu_standalone.sch]
2016-04-04 few more bug fixes
    [SNES_APU_SD.ino]
2016-04-12 File depth error handling. Current file bug fixed.
    [SNES_APU_SD.ino]
